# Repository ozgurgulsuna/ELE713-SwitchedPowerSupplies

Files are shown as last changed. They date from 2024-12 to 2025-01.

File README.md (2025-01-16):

# INTRODUCTION

This report presents the design and implementation of a forward converter that operates with an input voltage range of 36-60 V DC, providing a primary output of 5 V at 8 A along with a secondary auxiliary output of 12 V at 4 W. The forward converter is a type of DC-to-DC converter that transfers power during the forward operation of a transformer, making it suitable for applications requiring isolated and regulated outputs.

To achieve precise control over the output voltage, the design employs an analog controller integrated with a feedforward loop. The primary side of the converter utilizes a single switch, while the transformer flux is reset using an additional winding and a diode. This approach ensures efficient operation and prevents magnetic saturation of the transformer core.

In low-voltage, high-current applications, traditional diode-based rectification becomes less efficient due to the voltage drop across the diodes, typically around 0.5 V. To address this inefficiency, synchronous rectification is implemented using MOSFETs at the output. When conducting, a MOSFET with a 10-milliohm resistance produces a voltage drop of only 0.1 V at 10 A, significantly improving overall efficiency.

The printed circuit board (PCB) for this design is manufactured using a photolithography process. This process includes applying a photoresistive UV coating and etching the copper layer using a solution of hydrogen peroxide and hydrochloric acid. The circuit's functionality is thoroughly tested under various load conditions, including overload scenarios and auxiliary load operation, to validate its performance and reliability.

This report further discusses the chosen topology, magnetic design, and key considerations in achieving an efficient, compact, and robust forward converter design.

| Specification | |
|---|---|
| Input Voltage | 36-60 Vdc (Nominal 48Vdc) |
| Main Output Voltage | 5V (min. 4.9V, max. 5.1V) |
| Output Voltage Ripple | 100mV peak-to-peak |
| Main Output Nominal Current | 8A |
| Continuous Output Power | 40W (Main Output) |
| Overload Current | 9A |
| Auxiliary Output Voltage | 12V |
| Auxiliary Output Nominal Current| 0.3A |
| Auxiliary Output Power | 4W |
| Line Regulation | $\pm 0.2$% |
| Load Regulation | $\pm 0.5$% |
| Transient Peak Deviation | 10% of Vout (10% load to 100% @ 48 V) |
| Transient Response Recovery | 200 $\mu sec$ (10% load to 100% @ 48 V) |
| Overall Efficiency @ Full Load  |$\ge$ 80% |

---

# TOPOLOGY
The forward converter is a widely used topology in DC-to-DC conversion, especially for applications requiring electrical isolation and multiple outputs. This topology operates by transferring energy through a transformer during the on-state of the primary-side switch, with energy delivery controlled by the duty cycle of the switch. It is a buck-type converter implemented with the output LC filter structure.

Forward Converter
*Schematic of Forward Converter*

The duty ratio, defined as the proportion of time the primary switch is on during a switching cycle, is a critical parameter in determining the output voltage of the forward converter. The relationship between the input voltage, duty ratio, and transformer turns ratio governs the output voltage. A feedback mechanism ensures the duty ratio is adjusted dynamically to maintain a stable output under varying input and load conditions. In a forward converter, the maximum duty cycle is required to be less than 50% to ensure the transformer reset.

$${V_o \over V_i} = {Ns\over Np}*D$$

At the first cycle when the transistor T is ON, the transformer transfers power to the secondary side, and reset winding is reverse biased. In the second cycle, reset winding resets the transformer and supplies the magnetizing current back to the supply, and the load is supplied by the inductor and capacitor. Reset winding is very important to reset to transformer to prevent core saturation. In our design, we need to add two more windings to the transformer, one is to supply the primary side control circuitry, and another is to create the required 12V auxiliary supply.

The forward converter design includes a bias supply for the primary side, which provides the necessary power to the control circuitry and auxiliary components. This supply is derived from the bias winding connected to the primary side. The circuit initially starts with a voltage divider and a zener diode. As the bias winding experiences a change in flux, it supplies the rest of the circuit with the required voltage. The output of the bias winding is configured as a rectifier of a forward converter and is regulated with a linear regulator constructed from an NPN transistor. This sets the bias supply to approximately 12 volts.

bias
*Schematic of the Bias Voltage Generation Subcircuit.*

The secondary side of the converter includes an auxiliary output in addition to the primary output. This output is set to 12 volts and is rated for 0.3 amperes, resulting in a 4 W auxiliary output. The auxiliary output is supplied from another auxiliary winding with a forward rectifier output. This output is also regulated using a 12-volt linear regulator and is referenced to the ground of the secondary winding.

aux
*Schematic of the Auxiliary Voltage Generation Subcircuit.*

---

# MAGNETIC DESIGN

Magnetic design is a critical aspect of the forward converter, as it directly impacts efficiency, size, and reliability. The transformer in the forward converter serves two primary purposes: providing electrical isolation and stepping the voltage up or down based on the turn ratio.

A forward converter utilizes a transformer operating in forward mode, meaning that energy is transferred directly through the transformer core during the on-state of the primary switch. Unlike some other topologies, energy is not stored in the core during one cycle and transferred in the next; instead, the transfer is immediate.

The magnetic design is done in a MATLAB script that calculates key parameters for a forward converter, focusing on component sizing and operational constraints. It starts by defining input/output voltage ranges, power requirements, efficiency assumptions, and ripple constraints. The output current and its ripple are calculated to establish operating boundaries.

A significant part of the script focuses on determining the duty cycle range as a function of the transformer turns ratio $$(\N_1/N_2\)$$ and selecting an optimal ratio to ensure the converter operates within specified limits. Transformer design calculations include determining winding turns for primary, secondary, and auxiliary windings while ensuring compliance with voltage and current constraints, such as switch voltage limits. The calculated turn ratios are given in the table below.

| Winding | Turns |
|---|---|
| Primary | 10 |
| Reset | 10 |
| Secondary | 4 |
| Bias | 7 |
| Auxiliary | 7 |

*Selected Turns Ratios.*

The script calculates the magnetizing inductance $$\(L_m\)$$ and evaluates the impact of switching frequency on inductor performance. It also designs the output filter components to meet ripple voltage constraints.

Core selection is supported by area product $$\(A_p\)$$ calculations using various methods, ensuring the chosen core can handle the required flux and thermal limits. Wire gauge and winding distribution are calculated to balance current density and copper usage.

Finally, the script includes a loss analysis, estimating core and copper losses, and evaluating leakage inductance to ensure the design meets efficiency and performance goals. This approach focuses on key aspects of forward converter design while avoiding unnecessary complexity.

The code can be found in [magnetic design folder](%5B02%5D%20Magnetic%20Design/magnetic_design.m).

## TRANSFORMER REALIZATION ##

After evaluating the available cores, calculations are made, and a few candidate cores are chosen based on area product criteria. As a final decision, E30/15/7 3C94 is chosen (by Ferroxcube). There were smaller options; however, this core is favored considering the ease of implementation. Our switching frequency is chosen as 200kHz. At 200kHz, which is moderately high, we used $1 mm^2$ litz wires to avoid the skin effect and proximity effect. For the primary we have 10 turns with no parallel wires, at the secondary, we have 4 turns with 2 parallel wires. The auxiliary winding is winded using 0.2 $mm^2$ litz cable to have lower losses. Reset winding and primary bias circuitry are winded with thin copper cables so that they won't carry high currents. The order of windings is secondary-auxiliary-reset-bias-primary.

<div style="text-align: center;">
  PCB Preprocess
  <p><em>Transformer Windings Drawing</em></p>
</div>

---
# CONTROLLER DESIGN
For the controller, a specific analog integrated circuit, LT1952-1 produced by Analog Devices, is used to implement the controller. LT 1952-1 is a single-switch synchronous forward controller for forward controller designs within the range of 25-500 W. This controller is favored because it has the option to implement synchronous rectification. and high efficiencies can be achieved. LT1952 is the main controller; however, there are 2 more integrated circuits for the essential working of the converter. TL431 is used as a feedback compensator for controlling the output voltage. Moreover, LTC3900 is used for synchronous rectification which takes the SYNC signal from the LT1952-1 with the help of pulse transformer and switches two MOSFETs for improving the efficiency (with the risk of short-circuiting the secondary side MOSFETs).

---
# PRODUCTION AND ASSEMBLED PCB
The printed circuit board (PCB) for this design is manufactured using a photolithography process. This process includes applying a photoresistive UV coating and etching the copper layer using a solution of hydrogen peroxide and hydrochloric acid. The circuit's functionality is thoroughly tested under various load conditions, including overload scenarios and auxiliary load operation, to validate its performance and reliability.

<div style="text-align: center;">
  PCB Preprocess
  <p><em>Final Results of the etched PCB.</em></p>
</div>

<div style="text-align: center;">
  PCB Preprocess
  PCB Preprocess
  <p><em>Assembled PCB</em></p>
	        
</div>

## RESULTS ##
After the design is completed and assembled some measurements are taken. At first, some problems occurred at the current sense pin of the controller, which was due to a grounding problem. We solved it by fixing it. 
cs_fault
*Converter Output in the case of fault.*

After fixing that, tests were continued without synchronous switches which provided an efficiency of around 75%. We activated the synchronous rectification to increase efficiency and obtain better results. At this part, we had some problems with the synchronization and failed the synchronize both switches. However, synchronizing one switch had no disadvantage but a slight improvement so we obtained a  semi-synchronous converter. Forward converter without auxiliary is quite efficient; however, the auxiliary linear regulator creates quite a loss. The results are as follows:

5v_rated
*5V Rated Operation*
Ripple_v1
*Voltage Ripple Measurement*

Efficiency Calculations(@48V):

Only Forward Converter

${Efficiency} = {Pout \over Pin}$ =  $`{(5.15 × 7.21) \over (48.5 × 1.04)}`$ = 0.8602

Forward Converter with 4W auxiliary load

${Efficiency} = {Pout \over Pin}$ =  $`{(5.15 × 7.21 + 4.3) \over (48.5 × 1.04)}`$ = 0.8214

I would like to point out that @60V efficiency gets worse due to auxiliary efficiency. 

---

# CONCLUSION

In conclusion, there are several isolated DC-DC converter topologies with all their advantages
and disadvantages. In this project, forward converter topology is implemented to convert 36-
60V to 5V with the addition of 12V auxiliary voltage. Moreover, the project covers magnetic design, analog design, and feedback design
for isolated DC/DC converters. The design showed that the topology proved to be working;
however, there is still room for improvement in terms of PCB design, feedback design, and
magnetic design. 

---
# APPENDIX

```matlab
close all
clear 
clc
%% Specify project requirements

Vimax = 60;
Vimin = 36;
Vo = 5;
Po = 40;
Vaux = 12;
Paux = 4;

% Choose an estimated efficiency
eff_est = 0.82;

% Choose inductor ripple ratio (ismail wants this)
ripple_ratio = 0.1625;

% Voltage ripple defined by specifications
delta_Vo = 0.1;  % Vpp

Io = Po/Vo;
Io_max = Io + Io*ripple_ratio/2;
Io_min = Io - Io*ripple_ratio/2;

% Auxiliary
Iaux = Paux/Vaux;

%% Duty Range vs Turns Ratio
% We observe the effect of turns ratio on the duty range of our converter
% given the input and output voltage range

% Calculated turns ratio for forward converter
% Vo/Vin = D*N2/N1

N1 = 1;

% We sweep N1/N2 between 1 and 5
N2 = linspace(1,5.9,50);

Dmax_vec = zeros(1,50);
Dmin_vec = zeros(1,50);

% Calculate min and max duty values for all N values
for i=1:50
    d1 = ((N2(i)) * ((Vo+Io*0.05)/Vimin));  % output inductance resistance
    d2 = ((N2(i)) * ((Vo+Io*0.05)/Vimax));
    dmax = max(d1,d2);
    dmin = min(d1,d2);
    Dmax_vec(i) = dmax;
    Dmin_vec(i) = dmin;
end

fig1 = figure;
plot(N2/N1,Dmax_vec);
hold on
plot(N2/N1,Dmin_vec);
% draw a line for the duty cycle limit
plot([0 5.9], [0.39 0.39], 'r--');
% draw a line for n = 2.6
plot([2.6 2.6], [0 0.5], 'r--');
legend
grid minor
title("Duty cycle limits vs N")
legend("D_{max}", "D_{min}")
xlabel("Turns ratio N"), ylabel("Duty cycle")
ylim([0 0.5])
hold off
% exportgraphics(fig1, "../../4-Report/img/DvsN.pdf")

% from the duty ranges we can select 
% Dmax = 0.39  and
% N1/N2 = 2.6

N2  = 1/2.6 ;
Dmax = (Vo+Io*0.05)/Vimin/N2;
%% Transformer Design
% Switch Voltage Limit: 200 V
% Vsw >= Vimax + Vimax*N1/N3 + Vsnub

Vsnub = 10 ;  % approximately
Vsw_max = 120;
N3_min = 1/((Vsw_max - Vimax - Vsnub)/(Vimax*N1));
% Vimax+Vinmax*N1/N3+Vsnub;
% N3_min = (Vsw - Vimax - Vsnub)/Vimax ;

% Dmax should be less than the Dmax level
Dmax_limit = 1/(1+N3_min/N1) ;

% Pick N3 as 1
N3 = 1;
Dmax_limit = 1/(1+N3/N1) ;

%% Determine Lm
clear dmin dmax Dmin_vec Dmax_vec d1 d2 i N
% 
Vin_vec = linspace(60, 36, 50);
D_vec = ((Vo+Io*0.05)*N1./(Vin_vec*N2));
fs = linspace(50e3, 200e3, 50);
Lmvec = zeros(1,50);
% delta_ILm_vec = ones(50, 50);  % Initial guess for delta_ILm, e.g., 0.1 A

%
Lm = 200e-6;
Fsw = 200e3;

% for i = 1:50
%     for j = 1:50
%         Lmvec(j) = Vimin*Dmax/(fs(i)*delta_ILm_vec(j))
%         delta_ILm_vec(i,j) = Vimin*Dmax/(fs(i)*Lmvec(j));
%     end
% end

% plot(fs,delta_ILm_vec)

delta_ILm = Vimin*Dmax/(Fsw*Lm);

% Choose max duty as 0.3900, calculate N
N2 = Vo/(Dmax*Vimin);

% Auxulary winding
N4 = Vaux/(Dmax*Vimin);

% Check switch peak current 
Io_pk_ref = Io_max*N2/N1/0.92;  % eff estimate correct ?
Isw_min = Io_min*N2/N1/0.92;
Isw_peak = delta_ILm+Io_pk_ref;   

% Choose switching frequency
%SOLVE DOUBLE ITERATION TO FIND DELTA IL AND LM 

% Determine the transformer current ripple

% Find required Lm versus Fsw
for i=1:50
    Lmvec(i) = (Vimin*Dmax)/(fs(i)*delta_ILm);
end

fig2= figure;
plot(fs, Lmvec/1e-6);
grid minor
xlabel("Switching Frequency (Hz)"), ylabel("L_m value (H)")
title("Lm for the ripple constraint vs. Fsw")

Ireset = (delta_ILm*(N3/N1)*Dmax)/2*1.83;

Vreset = Vimin;

%% Transformer Design POT-Core
% https://www.tdk-electronics.tdk.com/download/519704/069c210d0363d7b4682d9ff22c2ba503/ferrites-and-accessories-db-130501.pdf
Kw = 0.4;

% Select Core Material (N49)
performance_factor = 20000;

% Area Product Calculation: First Method
J = 5e6; % Current Density (A/m^2)
delta_B = performance_factor/Fsw; % Flux Density Swing (T)
P_trans = Vo*Io + Vaux*Iaux + (Vo*Io + Vaux*Iaux)/eff_est+ Vreset*Ireset; % Transmitted Power (P)

% First Ap is from the lecture notes
% Area Product Calculation: Method-1
display("Method-1")
Ap = ((11.1*Vo*Io/eff_est)/(0.141*delta_B*Fsw))^(1.31)*1e4

% Area Product Calculation: Method-2
display("Method-2")
Ap = ((Vo*Io/eff_est)/(0.014*delta_B*Fsw))^(4/3)*1e4

% Area Product Calculation: Method-3
display("Method-3")
C = 0.71; % Converter Coefficient (Forward Converter)
Ap = P_trans/(C*delta_B*Fsw*J)*1e12

% Area Product Calculation: Method-4
display("Method-4")
Kconv = 0.5;
Ap = Kconv*P_trans/(Kw*Fsw*delta_B*J)*1e12

% Selected RM type Core (RM 8 N49)
Ac = 64e-6;
Aw = 10.8*(17-8.55)/2e6;
Ap_core_rm8 = Ac*Aw*1e12
Al = 2200; % (nH/N^2)

% % Selected RM type Core (RM 7 N49 )
% Ac = 43e-6;
% Aw = 8.4*(14.75-7.25)/2e6;
% Ap_core_rm7 = Ac*Aw*1e12
% Al = 1900; % (nH/N^2)

% Ac = 31.3e-6;
% Aw = 8*(12.6-6.4)/2e6;
% Ap_core_rm6 = Ac*Aw*1e12
% Al = 2400; % (nH/N^2)

% % Selected ETD type Core (E 20/10/6 EF20)
% Ac = 32e-6;
% Aw = 14*(14.1-5.9)/2e6;
% Ap_core = Ac*Aw
 
% % Selected PQ type Core (PQ20/20)
% Ac = 62.1e-6;
% Aw = 14.3*(18-8.8)/2e6;
% Ap_core = Ac*Aw
% Al = 5200 % (nH/N^2)

% % RM 10 N49
% Ac = 98e-6;
% Aw = 12.4*(21.2-10.9)/2e6;
% Ap_core = Ac*Aw*1e12
% Al = 2900; % (nH/N^2)

% 
% % RM 12
% Ac = 146e-6;
% Aw = 16.8*(25-12.8)/2e6;
% Ap_core = Ac*Aw
% Al = 5300; % (nH/N^2)

% % EFD 20/10/7
% Ac = 31e-6;
% Aw = 7.77*2*(15.4-8.9)/2;
% Ap_core = Ac*Aw*1e12
% Al = 910;

% % ETD 34/17/11
% Ac = 97.1e-6;
% Aw = 11.8*2*(25.6-11.1)/2e6;
% Ap_core_ETD = Ac*Aw*1e12
% Al = 2600;

% % P18/11 SER
% Ac = 43.3e-6;
% Aw = (14.9-7.60)/2*7.2/1e6;
% Ap_core_P18 = Ac*Aw*1e12
% Al = 260;

% % EF 25 6 11 N97
% Ac = 67.2e-6;
% Aw = (21.7-9.4)/2*6.2/1e6;
% Ap_core_EF25 = Ac*Aw*1e12
% Al = 4100;

% E30/15/7 3C94
Ac = 60e-6;
Aw = (19.5-7.2)/2*9.7*2/1e6;
Ap_core_E30 = Ac*Aw*1e12
Al = 1900;

% % E20/10/6
% Ac = 32e-6;
% Aw = (14.1-5.9)/2*7*2/1e6;
% Ap_core_E20 = Ac*Aw*1e12
% Al = 1350;

%% Turn Number and Saturation Calculations
% From primary side 
% Vp = N1 dΦ/dt

% Expected operation
Np = (Vimax)*D_vec(1)/(Fsw*delta_B*Ac);
Np = (Vimin)*Dmax/(Fsw*delta_B*Ac)

% At max instance, allow for max B. if turns ratio higher than this, core
% will not saturate.
B_sat = 0.3;

% Min turn numbers, less than that with saturate the core 
Np_min = (Vimax)*0.5/(Fsw*B_sat*Ac) 

Np = 10
Nr = 10

Ns_min = Np*N2
Naux_min = Np*N4

Ns = 4
Na = 10

% Np = 8  PRIMARY
% Nr = 8  RESET
% Ns = 3  SECONDARY
% Na = 6  AUX

% Let's back-calculate the core flux density
% Lm = Np dΦ/i in microhenries
Lm_core = Al*Np*Np*1e-9

% in Tesla
delta_B_core = Lm*delta_ILm/(Np*Ac)

% in Tesla
delta_B_core = Lm_core*delta_ILm/(Np*Ac) 

%% Wire Gauge Calculation
% Determine Cable Length and Type
% https://masteringelectronicsdesign.com/the-rms-value-of-a-trapezoidal-waveform-part-2/
% https://masteringelectronicsdesign.com/how-to-derive-the-rms-value-of-a-triangle-waveform/
% Primary side assume square type voltage

Isw_mean = (Isw_peak+Isw_min)/2;
Isw_rms = Isw_mean*sqrt(Dmax);
Isw_rms = sqrt(Dmax/3*(Isw_peak^2+Isw_peak*Isw_min+Isw_min^2));

Isw_avg = Isw_mean*Dmax

Ipri_rms = Isw_rms;
Isec_rms = sqrt(Dmax/3*(Io_max^2+Io_max*Io_min+Io_min^2))

Ireset_rms = delta_ILm*(N3/N1)*sqrt(Dmax/3);

Iaux_rms = sqrt(Dmax/3*((Iaux*1.2)^2+Iaux^2+(Iaux*0.9)^2))

% Winding Area Distribution

A1 = Ipri_rms*Np
A2 = Isec_rms*Ns
A3 = Ireset_rms*Nr
A4 = Iaux_rms*Na

Atotal = A1 + A2 + A3 + A4

A1 = A1/Atotal
A2 = A2/Atotal
A3 = A3/Atotal
A4 = A4/Atotal

Pri_copper_cs = A1*Kw*Aw/Np*1e6
Sec_copper_cs = A2*Kw*Aw/Ns*1e6
Reset_copper_cs = A3*Kw*Aw/Nr*1e6
Aux_copper_cs = A4*Kw*Aw/Na*1e6

Jp=Ipri_rms/Pri_copper_cs
Js=Isec_rms/Sec_copper_cs
Jr=Ireset_rms/Reset_copper_cs
Ja=Iaux_rms/Aux_copper_cs

%% Litz
% Determine Cable Length and Type

% Set cable diameters:

% https://www.elektrisola.com/en/Litz-Wire/Info
litz_packing_factor = 1.28 ;

% TO DO: winding configuration sec/2 : pri : sec/2

%% Output Filter Calculation

Cf_cross_Lf = (Vo*(1-D_vec(1)))/(Fsw^2*8*delta_Vo) 

Lf = 16e-6 % SRP1265CC-220M reduces to 16 uH @ 10 A
Cf_min = Cf_cross_Lf/Lf

Cf = (5 + 5 + 5)*1e-6 ; % uF

delta_Vo_calculated = ((1-D_vec(1)))/(8*Lf*Cf*Fsw^2)*Vo;

delta_Il_max = ((Ns/Np*Vimax-Vo)*(Dmax)/(Fsw*Lf))
delta_Il = ((Ns/Np*Vimax-Vo)*(D_vec(1))/(Fsw*Lf))
Il_peak = Po/Vo+delta_Il/2

Caux_cross_Laux = (Vaux*(1-D_vec(1)))/(Fsw^2*8*Vaux*0.2);
Laux = 2.2e-6;
Caux_min = Caux_cross_Laux/Laux;
Caux = (5 + 5)*1e-6 ; % uF

delta_Iaux_max = ((Vaux)*(1-Dmax)/(Fsw*Laux))  %% simulation check

%% Power Loss

% Core Loss
% https://elnamagnetics.com/wp-content/uploads/library/Ferroxcube-Materials/3C94_Material_Specification.pdf

% Coefficients (with 95% confidence bounds):
p1 =   8.892e-05;
p2 =     0.01501;
p3 =      -0.775;
p4 =       17.63;

P_density_center = p1.*(B_field_center.*1000.*ripple_ratio).^3 + p2.*(B_field_center.*1000.*ripple_ratio).^2 + p3.*(B_field_center.*1000.*ripple_ratio) + p4; % mT -> kW per m^3
P_center = P_density_center.*(C*D*F*2)*1000 ;% core center volume

P_density_sides = p1.*(B_field_sides.*1000.*ripple_ratio).^3 + p2.*(B_field_sides.*1000.*ripple_ratio).^2 + p3.*(B_field_sides.*1000.*ripple_ratio) + p4; % mT -> kW per m^3
P_sides = P_density_sides.*(((A-B)*F*2*D)+((B-C)*(D-E)*F*2))*1000 ;  % core center volume

P_core = (P_center + P_sides)*2 ; % an error margin of 200 % is given

% Copper Loss for litz wire
% AC losses proximity and skin effect can be ignored
% Length of the wires is estimated from the middle radius

end_winding_pri = 0.265;
end_winding_sec = 0.080;

lenght_pri = primary_cable_count*(2*(C+0.005+primary_cable_diameter/2)+2*(F+0.005+primary_cable_diameter/2));
lenght_sec = secondary_cable_count*(((A+B)/2*2)+(5e-3+F)*2) ;

R_meas_pri = 18e-3;
R_pri = (cu_resistivity*lenght_pri)/(primary_parallel*pi*(primary_cable_diameter/2)^2*primary_parallel/litz_packing_factor);
R_pri = R_meas_pri*lenght_pri/(lenght_pri+end_winding_pri);

R_meas_sec = 102e-3;
R_sec = (cu_resistivity*lenght_sec)/(secondary_parallel*pi*(secondary_cable_diameter/2)^2*secondary_parallel/litz_packing_factor);
R_sec = (R_meas_sec*lenght_sec/secondary_parallel)/(lenght_sec/secondary_parallel+end_winding_sec)

P_cu_pri = R_pri*5.3*5.3;
P_cu_sec = R_sec*1.45*1.45;

P_cu_total = P_cu_pri + P_cu_sec ;

% https://downloads.hindawi.com/archive/2012/635715.pdf
L_leak = (mu0*N_pri^2*((0.00016)*2+((B-C)/2))*(F*E+D*(C+2*(((B-C)/2)))))/(3*2^2*E^2);
```

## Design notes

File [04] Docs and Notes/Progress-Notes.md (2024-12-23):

- RM8 N49 Design (+)
- RM10 N49 Design (-)
- open loop simulation (+)
- Component olanlar listesi
- 0603 Sipariş
- PCB Çizimi
- Trafo Sarılması
- PCB Üretimi
- PCB Üzerine Parçaların Yerleştirilmesi
- PCB Testi

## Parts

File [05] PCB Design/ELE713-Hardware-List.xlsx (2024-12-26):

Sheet: Sheet1
Part Number | Digikey Link | Mouser Link | Türkiye Satıcı Link | Adet | Note/Comment
495-5259-ND | https://www.digikey.com/en/products/detail/epcos-tdk-electronics/B65811J0000R049/3914202 | https://www.mouser.com.tr/ProductDetail/EPCOS-TDK/B65811J0000R049?qs=%2FsLciWRBLmCTXJtOuixVPg%3D%3D | - | 2 | RM8 N49 CORE
495-5262-ND | https://www.digikey.com/en/products/detail/epcos-tdk-electronics/B65812A2203X000/3915527 | https://www.mouser.com.tr/ProductDetail/EPCOS-TDK/B65812A2203X?qs=fWY6JreybtlSEWdNz2ESCw%3D%3D | - | 6 | CLAMP RM 8
495-5268-ND | https://www.digikey.com/en/products/detail/epcos-tdk-electronics/B65812N1008D001/3914215 | https://www.mouser.com.tr/ProductDetail/EPCOS-TDK/B65812N1008D001?qs=%2FsLciWRBLmAhX8H95BubLg%3D%3D | - | 3 | BOBBIN COIL FORMER RM 8
495-5266-ND | https://www.digikey.com/en/products/detail/epcos-tdk-electronics/B65812C2005X000/3915529 | https://www.mouser.com.tr/ProductDetail/EPCOS-TDK/B65812C2005X000?qs=Uha62PnlbFACVqKod%252Bob5A%3D%3D | - | 2 | INSULATING WASHER RM 8
495-5279-ND | https://www.digikey.com/en/products/detail/epcos-tdk-electronics/B65813J0000R049/3914243 | https://www.mouser.com.tr/ProductDetail/EPCOS-TDK/B65813J0000R049?qs=%2FsLciWRBLmAzRqx%2FP15VyA%3D%3D | - | 2 | RM10 N49 CORE
495-5285-ND | https://www.digikey.com/en/products/detail/epcos-tdk-electronics/B65814B2203X000/3915532 | https://www.mouser.com.tr/ProductDetail/EPCOS-TDK/B65814B2203X000?qs=6jHPn5rTOgOwyQzQlqNzNA%3D%3D | - | 2 | CLAMP RM 10
495-5284-ND | https://www.digikey.com/en/products/detail/epcos-tdk-electronics/B65814B2005X000/3915531 | https://www.mouser.com.tr/ProductDetail/EPCOS-TDK/B65814B2005X000 | - | 2 | INSULATING WASHER RM 10
495-5288-ND | https://www.digikey.com/en/products/detail/epcos-tdk-electronics/B65814N1008D001/3914253 | https://www.mouser.com.tr/ProductDetail/EPCOS-TDK/B65814N1008D001?qs=vl78tpqlheehtyrm6TecxQ%3D%3D | - | 2 | BOBBIN COIL FORMER RM 10
1297-750341794CT-ND | https://www.digikey.com/en/products/detail/w%C3%BCrth-elektronik/750341794/22040896 | https://www.mouser.com.tr/ProductDetail/Wurth-Elektronik/750341794?qs=1Kr7Jg1SGW%252B6xH4BgiwnUw%3D%3D | - | 1 | XFMR FWD P-P DC/DC CONV 153UH TH
LT1952EGN-1#PBF-ND | https://www.digikey.com/en/products/detail/analog-devices-inc/LT1952EGN-1-PBF/960984 | https://www.mouser.com.tr/ProductDetail/Analog-Devices/LT1952EGN-1PBF?qs=ytflclh7QUVjPwCPnFQa%2Fw%3D%3D | - | 3 | IC REG CTRLR FWRD CONV 16SSOP
LTC3900ES8#PBF-ND | https://www.digikey.com/en/products/detail/analog-devices-inc/LTC3900ES8-PBF/962810 | https://www.mouser.com.tr/ProductDetail/Analog-Devices/LTC3900ES8PBF?qs=hVkxg5c3xu90E3KYcQK6pg%3D%3D | - | 3 | IC GATE DRVR LOW-SIDE 8SOIC
LT4430ES6#TRPBFCT-ND | https://www.digikey.com/en/products/detail/analog-devices-inc/LT4430ES6-TRPBF/960144 | https://www.mouser.com.tr/ProductDetail/Analog-Devices/LT4430ES6TRPBF?qs=hVkxg5c3xu%252BNUKU4M5kxpg%3D%3D | - | 2 | IC OPTOCOUPLER GATE DRVR SOT23-6
516-2390-5-ND | https://www.digikey.fi/en/products/detail/broadcom-limited/HCPL-M453-000E/1236261 | https://www.mouser.com.tr/ProductDetail/Broadcom-Avago/HCPL-M453-000E?qs=s%252BgfxR24RQ4WeIPwGyRm9Q%3D%3D | - | 2 | OPTOISO 3.75KV TRANSISTOR 6SOIC
296-36511-1-ND | https://www.digikey.com/en/products/detail/texas-instruments/CSD18563Q5A/4307641 | https://www.mouser.com.tr/ProductDetail/Texas-Instruments/CSD18563Q5A?qs=uSgeFhR2uNhOB1DXpy%2F30Q%3D%3D | - | 4 | MOSFET N-CH 60V 100A 8VSON
448-BSC094N06LS5ATMA1CT-ND | https://www.digikey.com/en/products/detail/infineon-technologies/BSC094N06LS5ATMA1/7428069 | https://www.mouser.com.tr/ProductDetail/Infineon-Technologies/BSC094N06LS5ATMA1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 | - | 4 | MOSFET N-CHANNEL 60V 47A 8TDSON
SIR690DP-T1-GE3CT-ND | https://www.digikey.com/en/products/detail/vishay-siliconix/SIR690DP-T1-GE3/6707767 | https://www.mouser.com.tr/ProductDetail/Infineon-Technologies/BSC094N06LS5ATMA1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 | - | 6 | MOSFET N-CH 200V 34.4A PPAK SO-8
MBR0540T3GOSCT-ND | https://www.digikey.com/en/products/detail/onsemi/MBR0540T3G/1477146?s=N4IgTCBcDaILICEBKAGArAFhQFQMwHEQBdAXyA | https://www.mouser.com.tr/ProductDetail/onsemi/MBR0540T3G?qs=3JMERSakebrRxZLCTBZZ9A%3D%3D | - | 5 | DIODE SCHOTTKY 40V 500MA SOD123
1727-4317-1-ND | https://www.digikey.com/en/products/detail/nexperia-usa-inc/BCX55-16-115/1692658 | https://www.mouser.com.tr/ProductDetail/Nexperia/BCX55-10115?qs=me8TqzrmIYW35YnvYvQrng%3D%3D | - | 2 | TRANS NPN 60V 1A SOT89
490-GRM31CR61A107MEA8LCT-ND | https://www.digikey.com/en/products/detail/murata-electronics/GRM31CR61A107MEA8L/16033775 | https://www.mouser.com.tr/ProductDetail/Samsung-Electro-Mechanics/CL31A107MPKNNWE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 | - | 4 | CAP CER 100UF 10V X5R 1206
994-Q4470-CLB |  | https://www.mouser.com.tr/ProductDetail/Coilcraft/Q4470-CLB?qs=BJlw7L4Cy799E8Om4qATXA%3D%3D |  | 1 | Pulse Transformers
1727-2893-1-ND | https://www.digikey.com/en/products/detail/nexperia-usa-inc/BAS516-115/763207 | https://www.mouser.com.tr/ProductDetail/Nexperia/BAS516115?qs=me8TqzrmIYVSb%2FgWSGcf7w%3D%3D |  | 5 | DIODE GEN PURP 100V 250MA SOD523
BAT760DICT-ND | https://www.digikey.com/en/products/detail/diodes-incorporated/BAT760-7/697106 | https://www.mouser.com.tr/ProductDetail/Diodes-Incorporated/BAT760-7?qs=JV7lzlMm3yKDDyO09xoRbQ%3D%3D |  | 4 | DIODE SCHOTTKY 30V 1A SOD323
553-2107-ND | https://www.digikey.com/en/products/detail/pulse-electronics/P0926NL/2265652 |  |  | 1 | PULSE XFMR 1:1:1 300UH
CSD19534Q5A | https://www.digikey.com/en/products/detail/texas-instruments/CSD19534Q5AT/4876343 | https://www.mouser.com.tr/ProductDetail/Texas-Instruments/CSD19534Q5AT?qs=s5SkPsIz10%252BKuhqaIOr9Yg%3D%3D | https://ozdisan.com/Product/Detail/594986/CSD19534Q5A | 4 | MOSFET N-CH 100V 50A 8VSON
KRL1632E-M-R022-F-T5 | https://www.digikey.com/en/products/detail/susumu/KRL1632E-M-R022-F-T5/3738000 |  | https://ozdisan.com/passive-components/resistors/smt-smd-and-chip-resistors/ERJ-8BWFR010V/994866 | 4 | SHUNT 0.022
BZG03C18-M3-08GICT-ND | https://www.digikey.com/en/products/detail/vishay-general-semiconductor-diodes-division/BZG03C18-M3-08/7898725 |  |  | 3 | DIODE ZENER 18V 1.25W DO214AC
BZT52C1213-FDICT-ND | https://www.digikey.com/en/products/detail/diodes-incorporated/BZT52C12-13-F/768854 |  |  | 3 | DIODE ZENER 12V 500MW SOD123
559-PS2801C-1-V-F3-ACT-ND | https://www.digikey.com/en/products/detail/renesas-electronics-corporation/PS2801C-1-V-F3-A/9564881 |  |  | 2 | OPTOISOLATOR 2.5KV TRANS 4SOIC
4423-CMK-R010-1.0CT-ND | https://www.digikey.com/en/products/detail/isabellenhuette-usa/CMK-R010-1-0/16733160 |  |  | 1 | RESISTOR - ISA-PLAN SHUNT, 0.01,
4423-CMP-R025-1.0CT-ND | https://www.digikey.com/en/products/detail/isabellenhuette-usa/CMP-R025-1-0/16836690 |  |  | 1 | RESISTOR - ISA-PLAN SHUNT, 0.025
4423-CMK-R050-1.0CT-ND | https://www.digikey.com/en/products/detail/isabellenhuette-usa/CMK-R050-1-0/16836592 |  |  | 1 | RESISTOR - ISA-PLAN SHUNT, 0.05,
399-A768MS107M1HLAE024CT-ND | https://www.digikey.com/en/products/detail/kemet/A768MS107M1HLAE024/12704540 |  |  | 3 | CAP ALUM POLY 100UF 20% 50V SMD
P16562CT-ND | https://www.digikey.com/en/products/detail/panasonic-electronic-components/35SVPF82M/4204894 |  |  | 2 | CAP ALUM POLY 82UF 20% 35V SMD
1189-2212-ND | https://www.digikey.com/en/products/detail/rubycon/250BXC100MEFC16X25/3564423 |  |  | 1 | CAP ALUM 100UF 20% 250V RADIAL
MC78M12BDTRKGOSCT-ND | https://www.digikey.com/en/products/detail/onsemi/MC78M12BDTRKG/1481467 |  |  | 2 | IC REG LINEAR 12V 500MA DPAK
MC7812CDTRKGOSCT-ND | https://www.digikey.com/en/products/detail/onsemi/MC7812CDTRKG/1481277 |  |  | 2 | IC REG LINEAR 12V 1A DPAK
118-SRP1265CC-220MCT-ND | https://www.digikey.com/en/products/detail/bourns-inc/SRP1265CC-220M/21263821 |  |  | 2 | IND SMD 22UH 10A
732-7427520CT-ND | https://www.digikey.com/en/products/detail/w%C3%BCrth-elektronik/7427520/16909847 |  |  | 1 | CMC 17A 2LN 30 OHM SMD
4587-C2220X225K251TCT-ND | https://www.digikey.com/en/products/detail/holy-stone-enterprise-co-ltd/C2220X225K251T/16895032 |  |  | 2 | CAP CER 2.2UF 250V X7R 2220
4587-C1206X221K202TCT-ND | https://www.digikey.com/en/products/detail/holy-stone-enterprise-co-ltd/C1206X221K202T/16895243 |  |  | 4 | CAP CER 220PF 2KV X7R 1206
18-01550900DRCT-ND | https://www.digikey.com/en/products/detail/littelfuse-inc/01550900DR/16627969 |  |  | 1 | 18-01550900DRCT-ND
5923-0680L5000-05CT-ND | https://www.digikey.com/en/products/detail/bel-fuse-inc/0680L5000-05/10440930 |  |  | 4 | FUSE BRD MNT 5A 125VAC/VDC 2SMD
5923-0679L8000-05CT-ND | https://www.digikey.com/en/products/detail/bel-fuse-inc/0679L8000-05/5844041 |  |  | 4 | FUSE BRD MNT 8A 125VAC/VDC 2SMD
SMD/DIP Çevirici TSSOP16 SSOP16 SO16 SOP16 | - | - | https://www.robotizmo.net/smd-dip-cevirici-tssop16-ssop16-so16-sop16-682 | 2 | SMD/DIP Çevirici

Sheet: Sheet2
Part Number | Digikey Link | Mouser Link | Türkiye Satıcı Link | Adet | Note/Comment
240-2501-1-ND | https://www.digikey.com/en/products/detail/laird-signal-integrity-products/CM3421Y600R-10/935982 |  |  | 1 | CMC 15A 2LN 60 OHM SMD
2156-LM340SX-12-ND | https://www.digikey.com/en/products/detail/rochester-electronics-llc/LM340SX-12/12592712 |  |  | 1 | IC REG LIN 12V 1A DDPAK/TO263-3
495-5080-ND | https://www.digikey.com/en/products/detail/epcos-tdk-electronics/b64290l0647x087/3913556 |  |  | 1 | FERRITE CORE TOROID 2.88UH N87
1727-3861-1-ND | https://www.digikey.com/en/products/detail/nexperia-usa-inc/PMEG2015EJ-115/1157680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 |  |  | 2 | DIODE SCHOTTKY 20V 1.5A SOD323F
PS2801-1ACT-ND | https://www.digikey.com/en/products/detail/cel/PS2801-1-F3-A/770595 |  |  | 1 | OPTOISOLATOR 2.5KV TRANS 4-SSOP
LTC3900ES8#PBF-ND | https://www.digikey.com/en/products/detail/analog-devices-inc/ltc3900es8-pbf/962810 |  |  | 1 | IC GATE DRVR LOW-SIDE 8SOIC
LT1952EGN-1#PBF-ND | https://www.digikey.com/en/products/detail/analog-devices-inc/LT1952EGN-1-PBF/960984 |  |  | 1 | IC REG CTRLR FWRD CONV 16SSOP
HAT2266H-EL-ECT-ND | https://www.digikey.com/en/products/detail/renesas-electronics-corporation/hat2266h-el-e/2328408 |  |  | 2 | MOSFET N-CH 60V 30A LFPAK
LT4430ES6#TRPBFCT-ND | https://www.digikey.com/en/products/detail/analog-devices-inc/LT4430ES6-TRPBF/960144 | https://www.mouser.com.tr/ProductDetail/Analog-Devices/LT4430ES6TRPBF?qs=hVkxg5c3xu%252BNUKU4M5kxpg%3D%3D | - | 1 | IC OPTOCOUPLER GATE DRVR SOT23-6
- | - | - | - | 2 | 13V ZENER
- | - | - | - | 2 | 18V ZENER
- | - | - | - | 3 | 0.5 R 1206
- | - | - | - | 1 | 33 nF 50 V C0G
- | - | - | - | 3 | 0.01R 1206 1W
- | - | - | - | 3 | PNP 45 V 0.1 A SOT23 | BASE ALIMNACAK TSSOP16
- | - | - | - | 1 | 0.1 uF X7R 1206
- | - | - | - | 1 | 182 R 1206
- | - | - | - | 1 | 2.2 R 1206
- | - | - | - | 1 | 1 uF 100V 1206
- | - | - | - | 2 | 7.5 V ZENER
- | - | - | - | 3 | 33 uF 25 V 1206
- | - | - | - | 2 | 100 pF 25V 1206 C0G
- | - | - | - | 1 | 100V 3 A SCHOTTKY
- | - | - | - | 2 | 360 R 1206
- | - | - | - | 2 | 365 R 1206
- | - | - | - | 1 | 220 pF 200 V 1206
- | - | - | - | 1 | 4.7 kR 1206
- | - | - | - | 2 | 10 pF 50 V THT
- | - | - | - | 1 | 4700 pF 50V C0G
- | - | - | - | 1 | 301 kR 1206
- | - | - | - | 2 | 200 kR 1206
- | - | - | - | 2 | 100 kR 1206
- | - | - | - | 1 | 82 kR 1206
- | - | - | - | 1 | 27 kR 1206
- | - | - | - | 1 | 22 kR 1206
- | - | - | - | 1 | 11kR 1206
- | - | - | - | 3 | 10 kR 1206
- | - | - | - | 6 | 220 uF 35 V CAP ALUM
- | - | - | - | 2 | PNP 60 V 1 A SOT89
- | - | - | - | 6 | 1200uF 16V THT ALUM
AP2204K-5.0TRG1DICT-ND | https://www.digikey.com/en/products/detail/diodes-incorporated/ap2204k-5-0trg1/4470810 |  |  | 3 | IC REG LINEAR 5V 150MA SOT23-5
LT1816CS8#PBF-ND | https://www.digikey.com/en/products/detail/analog-devices-inc/lt1816cs8-pbf/891580 |  |  | 3 | IC VOLTAGE FEEDBACK 2 CIRC 8SO
- | - | - | - | 15 | 0.1uF 16V 0603
- | - | - | - | 50 | 0R 603
- | - | - | - | 5 | 20kR 603
- | - | - | - | 20 | 3.3uF 25V 603
- | - | - | - | 5 | 2.43kR 0.5% 603
- | - | - | - | 5 | 1.4kR 0603
- | - | - | - | 5 | 20R 0.1% 0603
- | - | - | - | 5 | Thermistor NTC 10k 0603
- | - | - | - | 10 | 1000pF 50V 603
- | - | - | - | 3 | 61.9kR 0603

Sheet: Sheet3
Part Number | Özdisan Link veya TR | Adet | Note/Comment
495-5259-ND | https://www.digikey.com/en/products/detail/epcos-tdk-electronics/B65811J0000R049/3914202 | 2 | RM8 N49 CORE | DO NOT NEED
495-5262-ND | https://www.digikey.com/en/products/detail/epcos-tdk-electronics/B65812A2203X000/3915527 | 6 | CLAMP RM 8 | DO NOT NEED
495-5268-ND | https://www.digikey.com/en/products/detail/epcos-tdk-electronics/B65812N1008D001/3914215 | 3 | BOBBIN COIL FORMER RM 8 | DO NOT NEED
495-5266-ND | https://www.digikey.com/en/products/detail/epcos-tdk-electronics/B65812C2005X000/3915529 | 2 | INSULATING WASHER RM 8 | DO NOT NEED
495-5279-ND | https://www.digikey.com/en/products/detail/epcos-tdk-electronics/B65813J0000R049/3914243 | 2 | RM10 N49 CORE | DO NOT NEED
495-5285-ND | https://www.digikey.com/en/products/detail/epcos-tdk-electronics/B65814B2203X000/3915532 | 2 | CLAMP RM 10 | DO NOT NEED
495-5284-ND | https://www.digikey.com/en/products/detail/epcos-tdk-electronics/B65814B2005X000/3915531 | 2 | INSULATING WASHER RM 10 | DO NOT NEED
495-5288-ND | https://www.digikey.com/en/products/detail/epcos-tdk-electronics/B65814N1008D001/3914253 | 2 | BOBBIN COIL FORMER RM 10 | DO NOT NEED
1297-750341794CT-ND | https://www.digikey.com/en/products/detail/w%C3%BCrth-elektronik/750341794/22040896 | 1 | XFMR FWD P-P DC/DC CONV 153UH TH | DO NOT NEED
LT1952EGN-1#PBF-ND | https://www.digikey.com/en/products/detail/analog-devices-inc/LT1952EGN-1-PBF/960984 | 3 | IC REG CTRLR FWRD CONV 16SSOP | SPARE / SALVAGE
LTC3900ES8#PBF-ND | https://www.digikey.com/en/products/detail/analog-devices-inc/LTC3900ES8-PBF/962810 | 3 | IC GATE DRVR LOW-SIDE 8SOIC | SPARE / SALVAGE
LT4430ES6#TRPBFCT-ND | https://www.digikey.com/en/products/detail/analog-devices-inc/LT4430ES6-TRPBF/960144 | 2 | IC OPTOCOUPLER GATE DRVR SOT23-6 | SPARE / SALVAGE
TCMT1106 | https://www.ozdisan.com/optoelektronikler/optoelektronikler/transistor-ve-fotovoltaik-cikisli-optokuplorler/TCMT1106 | 4 | OPTOISOLATOR 3.75KV TRANS 4-SOP | ÖZDİSAN
CSD19534Q5A | https://ozdisan.com/power-semiconductors/mosfets/discrete-mosfets/CSD19534Q5A/594986 | 4 | MOSFET DIS.100V 50A N-CH VSONP-8 | ÖZDİSAN
CSD18563Q5A | https://ozdisan.com/guc-yari-iletkenleri/mosfetler/discrete-mosfetler/CSD18563Q5A?gad_source=1 https://ozdisan.com/power-semiconductors/mosfets/discrete-mosfets/CSD18540Q5B/582556 | 6 | MOSFET N-CH 60V 100A 8VSON | ÖZDİSAN
448-BSC094N06LS5ATMA1CT-ND | https://www.digikey.com/en/products/detail/infineon-technologies/BSC094N06LS5ATMA1/7428069 | 4 | MOSFET N-CHANNEL 60V 47A 8TDSON | DO NOT NEED
IRFH5020TRPBF | https://ozdisan.com/power-semiconductors/mosfets/discrete-mosfets/IRFH5020TRPBF/519539 https://karakoyelektronik.com/transistor/bsc320n20ns3g-87663 | 6 | MOSFET N-CH 200V 34.4A PPAK SO-8
MBR0540T3GOSCT-ND | https://ozdisan.com/Product/Detail/38953/MBR0540T1G | 5 | DIODE SCHOTTKY 40V 500MA SOD123 | ÖZDİSAN
BCX56-16,115 | https://ozdisan.com/power-semiconductors/transistors/discrete-transistors/BCX56-16115/344591 | 4 | TRANS NPN 60V 1A SOT89 | ÖZDİSAN
GRM32ER61A107ME20L- | https://ozdisan.com/passive-components/capacitors/smt-smd-and-mlcc-capacitors/GRM32ER61A107ME20L-/406631 | 5 | CAP CER 100UF 10V X5R 1206 | ÖZDİSAN
994-Q4470-CLB |  | 1 | Pulse Transformers | DO NOT NEED
BAS516,115 | https://ozdisan.com/power-semiconductors/diodes-diode-modules-and-rectifiers/general-purpose-diodes/BAS516115/529620 | 20 | DIODE GEN PURP 100V 250MA SOD523 | ÖZDİSAN
SBA140CS_R1_00001 | https://ozdisan.com/power-semiconductors/diodes-diode-modules-and-rectifiers/schottky-diodes/SBA140CSR100001/574222 | 5 | DIODE SCHOTTKY 30V 1A SOD323 | ÖZDİSAN
553-2107-ND | https://www.digikey.com/en/products/detail/pulse-electronics/P0926NL/2265652 | 1 | PULSE XFMR 1:1:1 300UH | SALVAGE
CMS-R020-1.0 | https://ozdisan.com/passive-components/resistors/precision-power-and-shunt-resistors/CMS-R020-1-0/582282 | 4 | RES.SHUNT (6432) 2512 20m Ohms 1% 2.5W AUTO SMT | ÖZDİSAN
1SMA5931_R1_00001 | https://ozdisan.com/power-semiconductors/diodes-diode-modules-and-rectifiers/zener-diodes/1SMA5931R100001/559779 | 5 | DIODE ZENER 18V 1.25W DO214AC | ÖZDİSAN
BZT52C12-TP | https://ozdisan.com/power-semiconductors/diodes-diode-modules-and-rectifiers/zener-diodes/BZT52C12-TP/648661 | 10 | DIODE ZENER 12V 500MW SOD123 | ÖZDİSAN
559-PS2801C-1-V-F3-ACT-ND | https://www.digikey.com/en/products/detail/renesas-electronics-corporation/PS2801C-1-V-F3-A/9564881 | 2 | OPTOISOLATOR 2.5KV TRANS 4SOIC | DO NOT NEED
SMK-R010-1.0 | https://ozdisan.com/passive-components/resistors/precision-power-and-shunt-resistors/SMK-R010-1-0/536411 | 2 | RESISTOR - ISA-PLAN SHUNT, 0.01, | ÖZDİSAN
VMS-R047-1.0-U | https://ozdisan.com/passive-components/resistors/precision-power-and-shunt-resistors/VMS-R047-1-0-U/536795 | 2 | RESISTOR - ISA-PLAN SHUNT, 0.05, | ÖZDİSAN
VR-035V181MG126-T/R | https://ozdisan.com/passive-components/capacitors/aluminum-capacitors/VR-035V181MG126-TR/585021 | 4 | CAP.EL.180uF 35V 10x12.6 MM 105C 2000H SMD | ÖZDİSAN
VR-080V470MG126-T/R | https://ozdisan.com/passive-components/capacitors/aluminum-capacitors/VR-080V470MG126-TR/956356 | 4 | CAP.EL.47uF 80V 10x12.60 105C 2000Hrs SMD | ÖZDİSAN
1189-2212-ND | https://www.digikey.com/en/products/detail/rubycon/250BXC100MEFC16X25/3564423 | 1 | CAP ALUM 100UF 20% 250V RADIAL
MC78M12CDTRKG | https://ozdisan.com/integrated-circuits-ics/power-management-ics/linear-voltage-regulators/MC78M12CDTRKG/353490 | 2 | IC REG LINEAR 12V 500MA DPAK | ÖZDİSAN
MC7812CDTRKG | https://ozdisan.com/integrated-circuits-ics/power-management-ics/linear-voltage-regulators/MC7812CDTRKG/603063 | 3 | IC REG LINEAR 12V 1A DPAK | ÖZDİSAN
IHLP5050FDER100M01 | https://ozdisan.com/passive-components/inductors/fixed-inductors/IHLP5050FDER100M01/589695 | 3 | INDUCTOR FIXED 10uH 20% SMD | ÖZDİSAN
SRI1209-100M | https://ozdisan.com/passive-components/inductors/fixed-inductors/SRI1209-100M/530619 | 2 | INDUCTOR POWER 10UH 12X12MM SMD | ÖZDİSAN
118-SRP1265CC-220MCT-ND | https://www.digikey.com/en/products/detail/bourns-inc/SRP1265CC-220M/21263821 | 2 | IND SMD 22UH 10A | DO NOT NEED
732-7427520CT-ND | https://www.digikey.com/en/products/detail/w%C3%BCrth-elektronik/7427520/16909847 | 1 | CMC 17A 2LN 30 OHM SMD | SPARE / SALVAGE
MC20KTB251225 | https://ozdisan.com/passive-components/capacitors/smt-smd-and-mlcc-capacitors/MC20KTB251225/1201518 | 6 | MLCC (5750) 2220 2.2uF 250VDC ±10% X7R | ÖZDİSAN
CL31C221JIHNNNE | https://ozdisan.com/passive-components/capacitors/smt-smd-and-mlcc-capacitors/CL31C221JIHNNNE/523539 | 10 | MLCC (3216) 1206 220pF 1000VDC ±5% C0G (NP0) | ÖZDİSAN
0154010.DR | https://ozdisan.com/circuit-protections/fuse-components/fuses/0154010-DR/612871 | 1 | FUSE BOARD MOUNT 10A 125VDC 2-SMD | ÖZDİSAN
0154005.DR | https://ozdisan.com/circuit-protections/fuse-components/fuses/0154005-DR/669001 | 1 | FUSE BRD MNT 5A 125VAC/VDC 2SMD | ÖZDİSAN
SET1500 | https://ozdisan.com/circuit-protections/fuse-components/fuses/SET1500/473352 | 10 | FUSE SMD 5A 250V 6125 TIME-LAG | ÖZDİSAN
SFE1800 | https://ozdisan.com/circuit-protections/fuse-components/fuses/SFE1800/994485 | 12 | FUSE SMD 8A 125V 2SMD FAST ACTING | ÖZDİSAN
SMD/DIP Çevirici TSSOP16 SSOP16 SO16 SOP16 | - | 2 | SMD/DIP Çevirici | BOUGHT

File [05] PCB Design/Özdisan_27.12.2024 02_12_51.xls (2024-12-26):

 | 27.12.2024
Fatura Adresim
Fatura adresi seçilmedi.
Görsel | Ürün Kodu | Ürün Açıklama | Birim Fiyat | KDV | Adet | KDV Dahil
 | VR-035V181MG126-T/R | CAP.EL.180uF 35V 10x12.6 MM 105C 2000H SMD | 0,7027700 USD | 20,00 % | 4 | 3,37 USD
 | SFE1800 | FUSE SMD 8A 125V 2SMD FAST ACTING | 0,1079700 USD | 20,00 % | 12 | 1,55 USD
 | IHLP5050FDER100M01 | INDUCTOR FIXED 10uH 20% SMD | 1,8785300 USD | 20,00 % | 3 | 6,76 USD
 | BCX56-16,115 | TRANSISTOR DIS.1A 80V NPN SOT89 MED.POWER SMT | 0,0337300 USD | 20,00 % | 4 | 0,16 USD
 | CSD19534Q5A | MOSFET DIS.100V 50A N-CH VSONP-8 | 0,3787900 USD | 20,00 % | 4 | 1,82 USD
 | MC20KTB251225 | MLCC (5750) 2220 2.2uF 250VDC ±10% X7R | 0,4115900 USD | 20,00 % | 6 | 2,96 USD
 | SBA140CS_R1_00001 | DIODE SCHOTTKY 1A 40V SOD323 SMT | 0,0447700 USD | 20,00 % | 5 | 0,27 USD
 | SET1500 | FUSE SMD 5A 250V 6125 TIME-LAG | 0,1079700 USD | 20,00 % | 10 | 1,30 USD
 | VMS-R047-1.0-U | RES.SHUNT (6432) 2512 47m Ohms 1% 4W AUTO SMT | 0,9272500 USD | 20,00 % | 2 | 2,23 USD
 | BZT52C12-TP | DIODE ZENER 500mW 12V ±5% SOD123 | 0,0143600 USD | 20,00 % | 10 | 0,17 USD
 | CMS-R020-1.0 | RES.SHUNT (6432) 2512 20m Ohms 1% 2.5W AUTO SMT | 0,5433800 USD | 20,00 % | 4 | 2,61 USD
 | 1SMA5931_R1_00001 | DIODE ZENER 1.5W 18V ±5% DO214AC (SMA) SMT | 0,1163900 USD | 20,00 % | 5 | 0,70 USD
 | CL31C221JIHNNNE | MLCC (3216) 1206 220pF 1000VDC ±5% C0G (NP0) | 0,1868800 USD | 20,00 % | 10 | 2,24 USD
 | MC7812CDTRKG | IC-7812 REG LINEAR 12V 1A DPAK | 0,1981200 USD | 20,00 % | 3 | 0,71 USD
 | GRM32ER61A107ME20L- | MLCC (3225) 1210 100UF 10VDC X5R | 1,0300200 USD | 20,00 % | 5 | 6,18 USD
 | TCMT1106 | IC-1106 OPTOISOLATOR 3.75KV TRANS 4-SOP | 0,1861400 USD | 20,00 % | 4 | 0,89 USD
 | VR-080V470MG126-T/R | CAP.EL.47uF 80V 10x12.60 105C 2000Hrs SMD | 0,4075600 USD | 20,00 % | 4 | 1,96 USD
 | SMK-R010-1.0 | RES.SHUNT (3216) 1206 10m Ohms 1% 1W AUTO SMT | 1,3434300 USD | 20,00 % | 2 | 3,22 USD
 | 0154010.DR | FUSE BOARD MOUNT 10A 125VDC 2-SMD | 2,6856500 USD | 20,00 % | 1 | 3,22 USD
 | MC78M12CDTRKG | IC-7812 V.REG.+12V 0,5A SMD TO252 (DPAK) | 0,1706300 USD | 20,00 % | 2 | 0,41 USD
 | MBR0540T1G | DIODE SCHOTTKY 500mA 40V SOD123-5 SMD ON | 0,0573600 USD | 20,00 % | 5 | 0,34 USD
 | CSD18563Q5A | MOSFET DIS.100A 60V N-CH 8SON | 0,4628100 USD | 20,00 % | 6 | 3,33 USD
 | BAS516,115 | DIODE 100V 250MA SOD523 | 0,0206300 USD | 20,00 % | 20 | 0,50 USD
 | 0154005.DR | FUSE BRD MNT 5A 125VAC/VDC 2SMD | 2,5118500 USD | 20,00 % | 1 | 3,01 USD
Toplam Tutar Detayı
Toplam Sipariş Tutarı | 41,61 USD
Kargo Fiyatı | 0,00 USD
KDV | 8,32 USD
Genel Toplam | 49,93 USD
Döviz Kuru | 35,31960 TRY
Ödenecek Tutar | 1763,54 TRY
 | Özdisan Elektronik A.Ş. DES Sanayi Sitesi 104 Sokak A07 Blok No : 54 - 56 Yukarı Dudullu / Ümraniye / İstanbul - Türkiye T : +90 216 420 18 82 F : +90 216 466 36 82

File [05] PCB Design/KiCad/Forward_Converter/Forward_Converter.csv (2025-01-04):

Reference | Value | Footprint | Qty
C1,C8,C16 | 2.2nF | 805 | 3
C2,C12,C13 | 100nF | 805 | 3
C3 | OC | 805 | 1
C6,C7,C11 | 2.2uF | -- mixed values -- | 3
C10,C14,C37,C45 | 10u | Capacitor_SMD:C_1210_3225Metric | 4
C15,C18,C20,C22,C27 | 1uF | -- mixed values -- | 5
C17,C26,C30,C31,C33,C39,C42,C44 | 100n | 805 | 8
C19,C23,C25,C32,C35 | 2.2u | Capacitor_SMD:C_2220_5750Metric | 5
C21 | 100pF | Capacitor_SMD:C_1206_3216Metric | 1
C24 | 220pF | Capacitor_SMD:C_1206_3216Metric | 1
C28 | 100p | 805 | 1
C29 | 470p | 805 | 1
C34 | 220p | 805 | 1
C36 | 10n | 805 | 1
R1 | 12k | 805 | 1
R2 | 18k | 805 | 1
R3 | 12R | 805 | 1
R4,R7,R10,R17 | 10k | 805 | 4
R5 | 180k | 805 | 1
R6 | 240k | 805 | 1
R11,R14 | 0R | 805 | 2
R12,R16,R26 | 4.7k | 805 | 3
R13,R30 | 100k | 805 | 2
R15 | 0R | 805 | 1
R18 | 160k | 805 | 1
R19 | 47R | 805 | 1
R20 | 220R | 805 | 1
R21 | 1.2k | 805 | 1
R22 | 360R | 1206 | 1
R23 | 182R | 1206 | 1
R24 | 365R | 1206 | 1
R25,R28 | 25R | 805 | 2
R27,R29 | 22k | 805 | 2
R31 | 8.2k | 805 | 1
R32 | 1k | 805 | 1
R33 | 200k | 805 | 1
R34 | 27k | 805 | 1

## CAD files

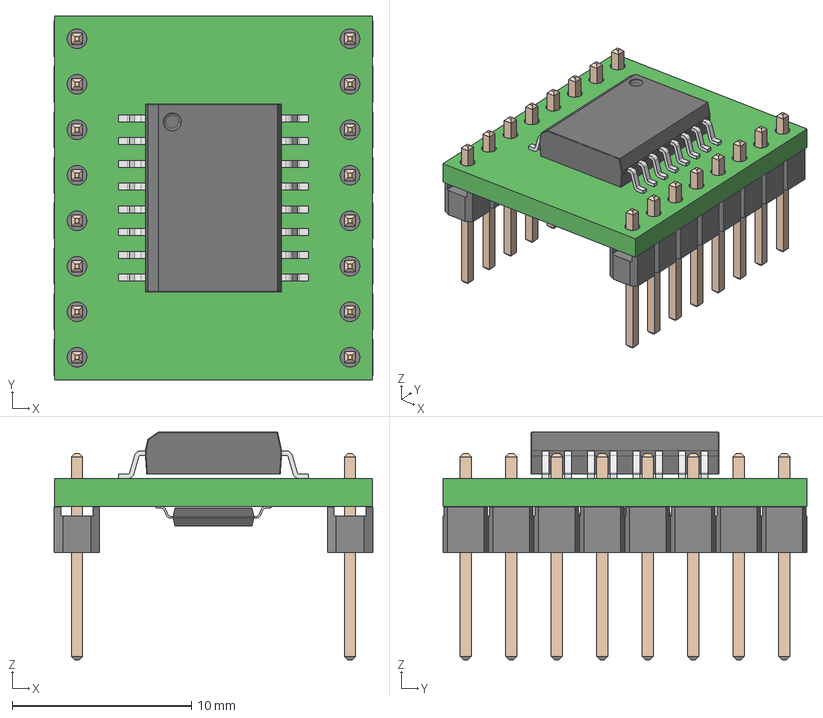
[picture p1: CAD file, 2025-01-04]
[05] PCB Design/3D/SO16 or TSSOP16 to DIL Adapter.step
17.8 x 20.3 x 12.7 mm
Board
User_Library-TSSOP-16_5.1x4.4_pin_TSSOP_tssop_1 x 16
User_Library-TSSOP-16_5.1x4.4_body_TSSOP_TSSOP_5.1x4.5_1
User_Library-SOIC-16-300_SOIC_300_SOIC_10.5X7.6_1
User_Library-SOIC-16-300_pin_SOIC_SO-300_1 x 16
6130xx11121_PIN x 16

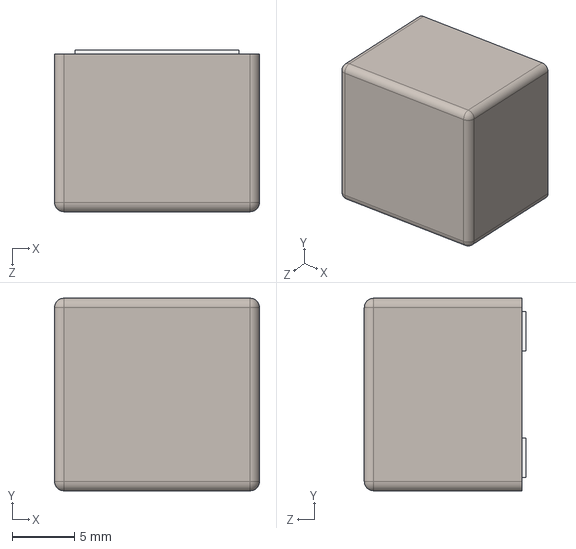
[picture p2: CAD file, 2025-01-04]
[05] PCB Design/3D/SRP1513CA-220M.stp
16.5 x 15.5 x 13.0 mm

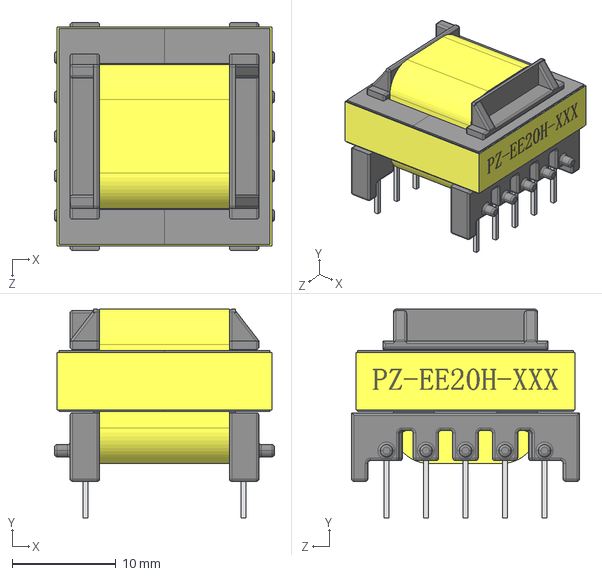
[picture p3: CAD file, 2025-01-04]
[05] PCB Design/3D/EE20H 5+5 transforer.STEP
21.2 x 20.1 x 22.0 mm

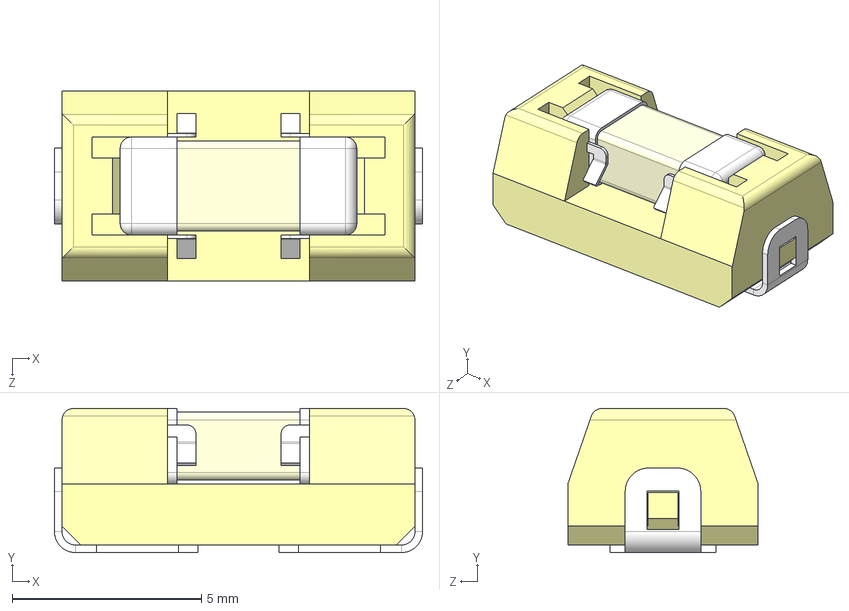
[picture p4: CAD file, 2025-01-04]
[05] PCB Design/3D/0154010.DR.step
9.73 x 3.81 x 5.03 mm

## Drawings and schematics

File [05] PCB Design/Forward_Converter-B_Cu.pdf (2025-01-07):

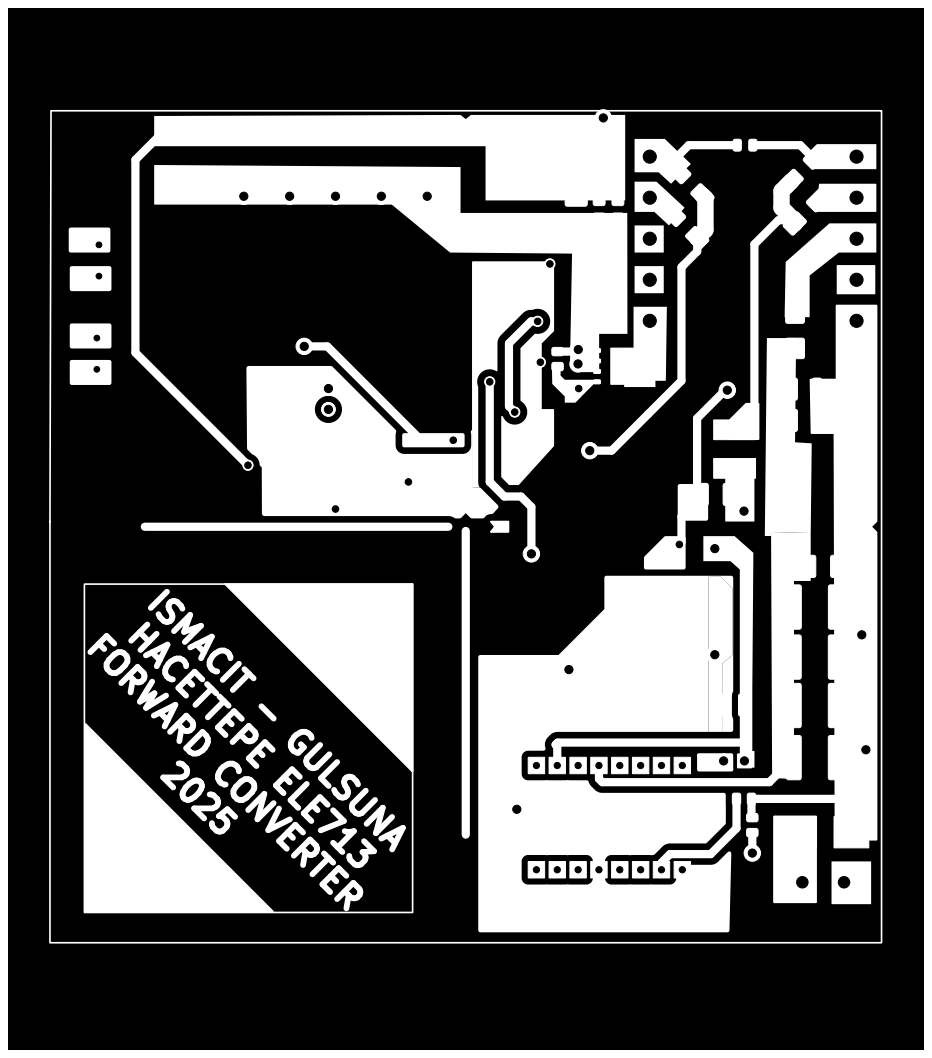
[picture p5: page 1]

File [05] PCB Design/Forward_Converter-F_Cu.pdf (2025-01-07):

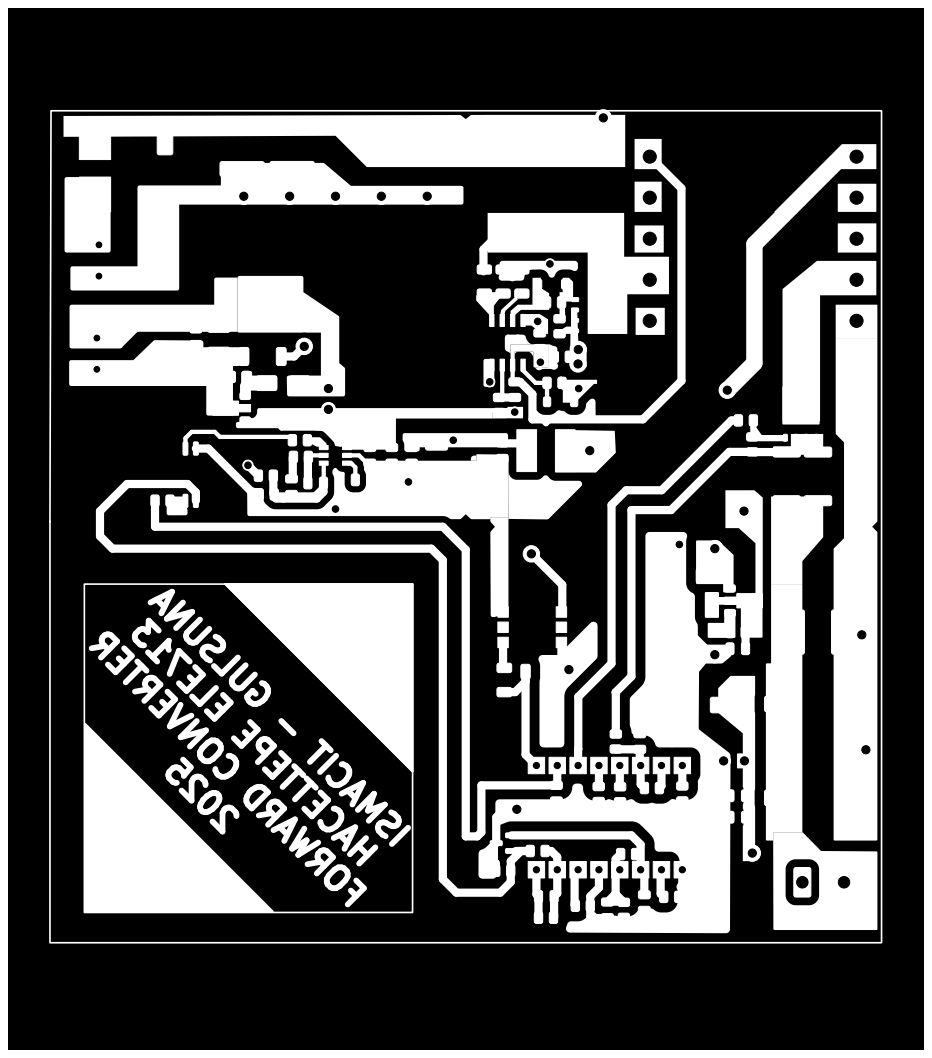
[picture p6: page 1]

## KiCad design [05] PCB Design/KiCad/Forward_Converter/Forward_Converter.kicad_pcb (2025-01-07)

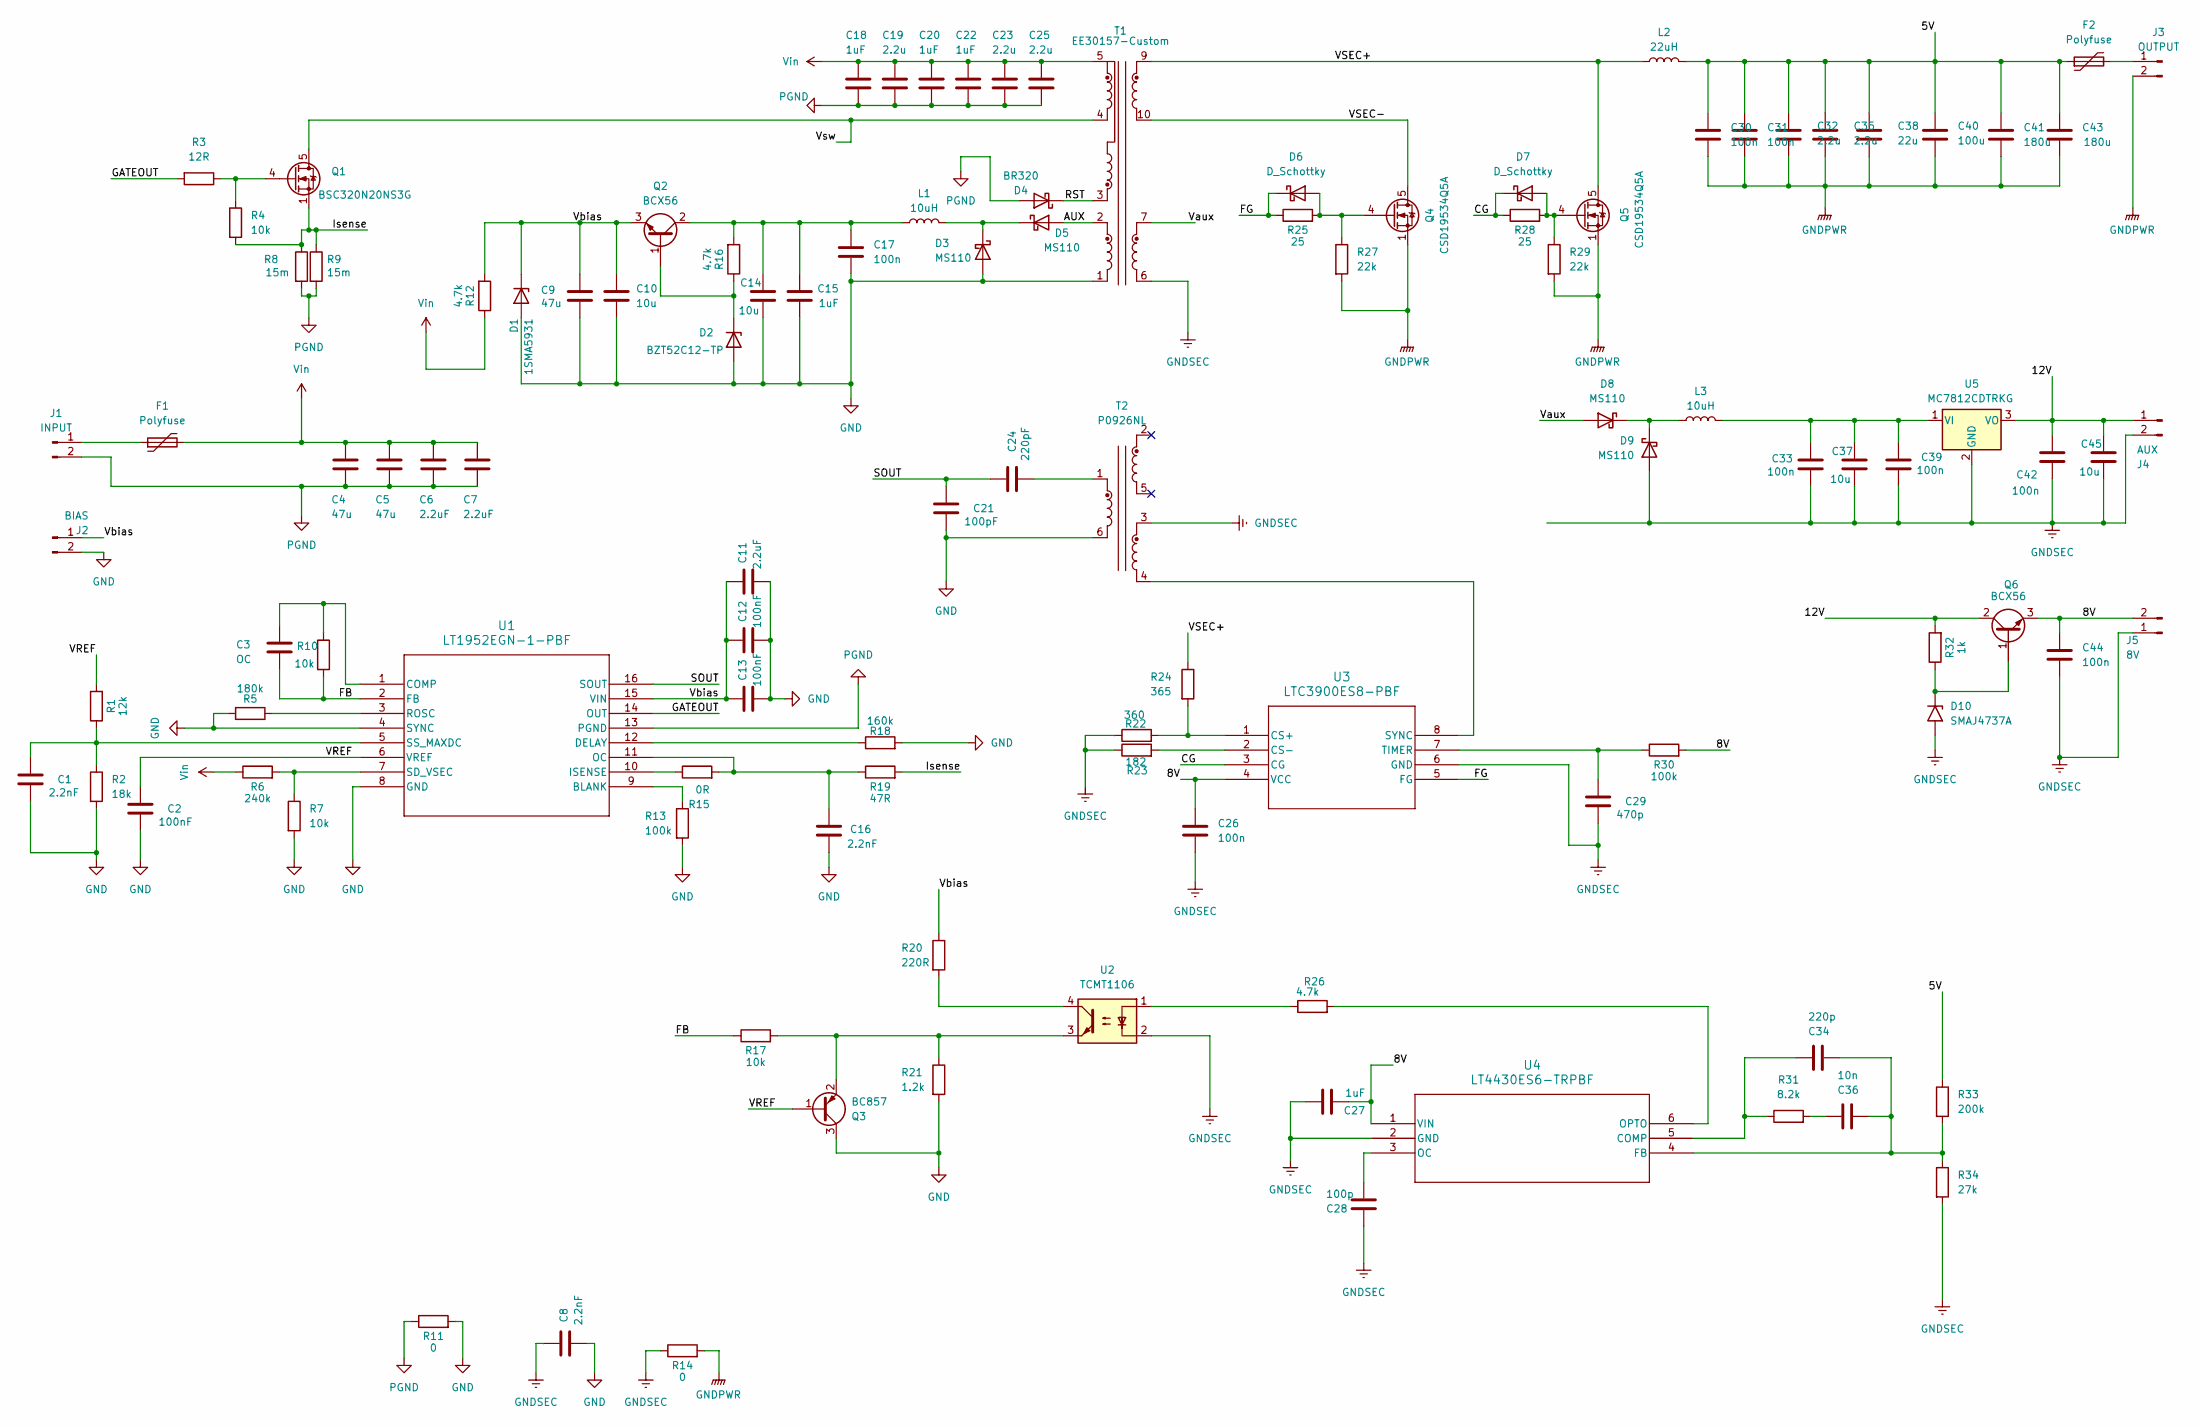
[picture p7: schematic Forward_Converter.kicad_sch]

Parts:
C1, C8, C16: 2.2nF; C_0805_2012Metric
C2, C12, C13: 100nF; C_0805_2012Metric
C3: OC; C_0805_2012Metric
C4, C5, C9: 47u; CP_Elec_10x12.6
C6, C7: 2.2uF; C_2220_5750Metric
C10, C14, C37, C45: 10u; C_1210_3225Metric
C11: 2.2uF; C_0805_2012Metric
C15, C18, C20, C22: 1uF; C_1210_3225Metric
C17, C26, C30, C31, C33, C39, C42, C44: 100n; C_0805_2012Metric
C19, C23, C25, C32, C35: 2.2u; C_2220_5750Metric
C21: 100pF; C_1206_3216Metric
C24: 220pF; C_1206_3216Metric
C27: 1uF; C_0805_2012Metric
C28: 100p; C_0805_2012Metric
C29: 470p; C_0805_2012Metric
C34: 220p; C_0805_2012Metric
C36: 10n; C_0805_2012Metric
C38: 22u; C_1210_3225Metric
C40: 100u; D_SMC
C41, C43: 180u; CP_Elec_10x12.6
D1: 1SMA5931; D_SMA
D2: BZT52C12-TP; D_SOD-123
D3, D5, D8, D9: MS110; D_SMA
D4: BR320; D_SMB
D6, D7: D_Schottky; D_SOD-123
D10: SMAJ4737A; D_SMA
F1, F2: Polyfuse; 0154010.DR
J1: INPUT; PhoenixContact_MSTBA_2,5_2-G-5,08_1x02_P5.08mm_Horizontal
J2: BIAS; PinHeader_1x02_P2.54mm_Vertical
J3: OUTPUT; TerminalBlock_MetzConnect_Type086_RT03402HBLC_1x02_P3.81mm_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
J4: AUX; TerminalBlock_MetzConnect_Type086_RT03402HBLC_1x02_P3.81mm_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
J5: 8V; PinHeader_1x02_P2.54mm_Vertical
L1, L3: 10uH; IND_VLS6045EX-100M-H
L2: 22uH; SRP1513CA8R2M_V2
Q1: BSC320N20NS3G; TDSON-8-1
Q2, Q6: BCX56; SOT-89-3
Q3: BC857; SOT-23
Q4, Q5: CSD19534Q5A; TDSON-8-1
R1: 12k; R_0805_2012Metric
R2: 18k; R_0805_2012Metric
R3: 12R; R_0805_2012Metric
R4, R7, R10, R17: 10k; R_0805_2012Metric
R5: 180k; R_0805_2012Metric
R6: 240k; R_0805_2012Metric
R8, R9: 15m; R_2512_6332Metric
R11, R14: 0; R_0805_2012Metric
R12, R16, R26: 4.7k; R_0805_2012Metric
R13, R30: 100k; R_0805_2012Metric
R15: 0R; R_0805_2012Metric
R18: 160k; R_0805_2012Metric
R19: 47R; R_0805_2012Metric
R20: 220R; R_0805_2012Metric
R21: 1.2k; R_0805_2012Metric
R22: 360; R_1206_3216Metric
R23: 182; R_1206_3216Metric
R24: 365; R_1206_3216Metric
R25, R28: 25; R_0805_2012Metric
R27, R29: 22k; R_0805_2012Metric
R31: 8.2k; R_0805_2012Metric
R32: 1k; R_0805_2012Metric
R33: 200k; R_0805_2012Metric
R34: 27k; R_0805_2012Metric
T1: EE30157-Custom
T2: P0926NL; Pulse_P0926NL
U1: LT1952EGN-1-PBF; SOP16 DIP Adapter
U2: TCMT1106; SOP-4_4.4x2.6mm_P1.27mm
U3: LTC3900ES8-PBF; SO-8_S_LIT
U4: LT4430ES6-TRPBF; TSOT-23_S6_LIT-M
U5: MC7812CDTRKG; TO-252-2

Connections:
/5V: C30.1, C31.1, C32.1, C35.1, C38.1, C40.1, C41.1, C43.1, F2.1, L2.2, R33.1
/8V: C26.1, C27.1, C44.1, J5.2, Q6.3 (E), R30.2, U3.4 (VCC), U4.1 (VIN)
/12V: C42.1, C45.1, J4.1, Q6.2 (C), R32.2, U5.3 (VO)
/AUX: D5.2 (A), T1.2
/CG: D7.1 (K), R28.1, U3.3 (CG)
/FB: C3.1, R10.2, R17.1, U1.2 (FB)
/FG: D6.1 (K), R25.1, U3.5 (FG)
/GATEOUT: R3.2, U1.14 (OUT)
/Isense: Q1.1 (S), Q1.2 (S), Q1.3 (S), R4.2, R8.1, R9.1, R19.2
/RST: D4.1 (K), T1.3
/SOUT: C21.2, C24.2, U1.16 (SOUT)
/VREF: C2.2, Q3.1 (B), R1.2, U1.6 (VREF)
/VSEC+: L2.1, Q5.5 (D), R24.1, T1.9
/VSEC-: Q4.5 (D), T1.10
/Vaux: D8.2 (A), T1.7
/Vbias: C9.1, C10.1, C11.2, C12.2, C13.2, D1.1 (K), J2.1, Q2.3 (E), R12.2, R20.1, U1.15 (VIN)
/Vsw: Q1.5 (D), T1.4
GND: C1.1, C2.1, C8.1, C9.2, C10.2, C11.1, C12.1, C13.1, C14.2, C15.2, C16.1, C17.2, C21.1, D1.2 (A), D2.2 (A), D3.2 (A), J2.2, Q3.3 (C), R2.2, R5.2, R7.2, R11.2, R13.2, R18.2, R21.2, T1.1, T1.8, T2.6, U1.4 (SYNC), U1.8 (GND)
GNDPWR: C30.2, C31.2, C32.2, C35.2, C38.2, C40.2, C41.2, C43.2, J3.2, Q4.1 (S), Q4.2 (S), Q4.3 (S), Q5.1 (S), Q5.2 (S), Q5.3 (S), R14.2, R27.2, R29.2
GNDSEC: C8.2, C26.2, C27.2, C28.2, C29.1, C33.2, C37.2, C39.2, C42.2, C44.2, C45.2, D9.2 (A), D10.2 (A2), J4.2, J5.1, R14.1, R22.1, R23.1, R34.2, T1.6, T2.3, U2.2, U3.6 (GND), U4.2 (GND), U5.2 (GND)
unnamed: C24.1, T2.1
unnamed: C36.2, R31.2
unnamed: D2.1 (K), Q2.1 (B), R16.1
unnamed: D3.1 (K), D5.1 (K), L1.2
unnamed: D6.2 (A), Q4.4 (G), R25.2, R27.1
unnamed: D7.2 (A), Q5.4 (G), R28.2, R29.1
unnamed: D8.1 (K), D9.1 (K), L3.1
unnamed: D10.1 (A1), Q6.1 (B), R32.1
unnamed: F1.1, J1.1
unnamed: F2.2, J3.1
unnamed: Q1.4 (G), R3.1, R4.1
unnamed: C14.1, C15.1, C17.1, L1.1, Q2.2 (C), R16.2
unnamed: Q3.2 (E), R17.2, R21.1, U2.3
unnamed: R20.2, U2.4
unnamed: R26.1, U2.1
unnamed: R13.1, U1.9 (BLANK)
unnamed: C3.2, R10.1, U1.1 (COMP)
unnamed: R18.1, U1.12 (DELAY)
unnamed: R15.1, U1.10 (ISENSE)
unnamed: C16.2, R15.2, R19.1, U1.11 (OC)
unnamed: R5.1, U1.3 (ROSC)
unnamed: R6.2, R7.1, U1.7 (SD_VSEC)
unnamed: C1.2, R1.1, R2.1, U1.5 (SS_MAXDC)
unnamed: R22.2, R24.2, U3.1 (CS+)
unnamed: R23.2, U3.2 (CS-)
unnamed: T2.4, U3.8 (SYNC)
unnamed: C29.2, R30.1, U3.7 (TIMER)
unnamed: C34.2, R31.1, U4.5 (COMP)
unnamed: C34.1, C36.1, R33.2, R34.1, U4.4 (FB)
unnamed: C28.1, U4.3 (OC)
unnamed: R26.2, U4.6 (OPTO)
unnamed: C33.1, C37.1, C39.1, L3.2, U5.1 (VI)
PGND: C4.2, C5.2, C6.2, C7.2, C18.2, C19.2, C20.2, C22.2, C23.2, C25.2, D4.2 (A), J1.2, R8.2, R9.2, R11.1, U1.13 (PGND)
Vin: C4.1, C5.1, C6.1, C7.1, C18.1, C19.1, C20.1, C22.1, C23.1, C25.1, F1.2, R6.1, R12.1, T1.5

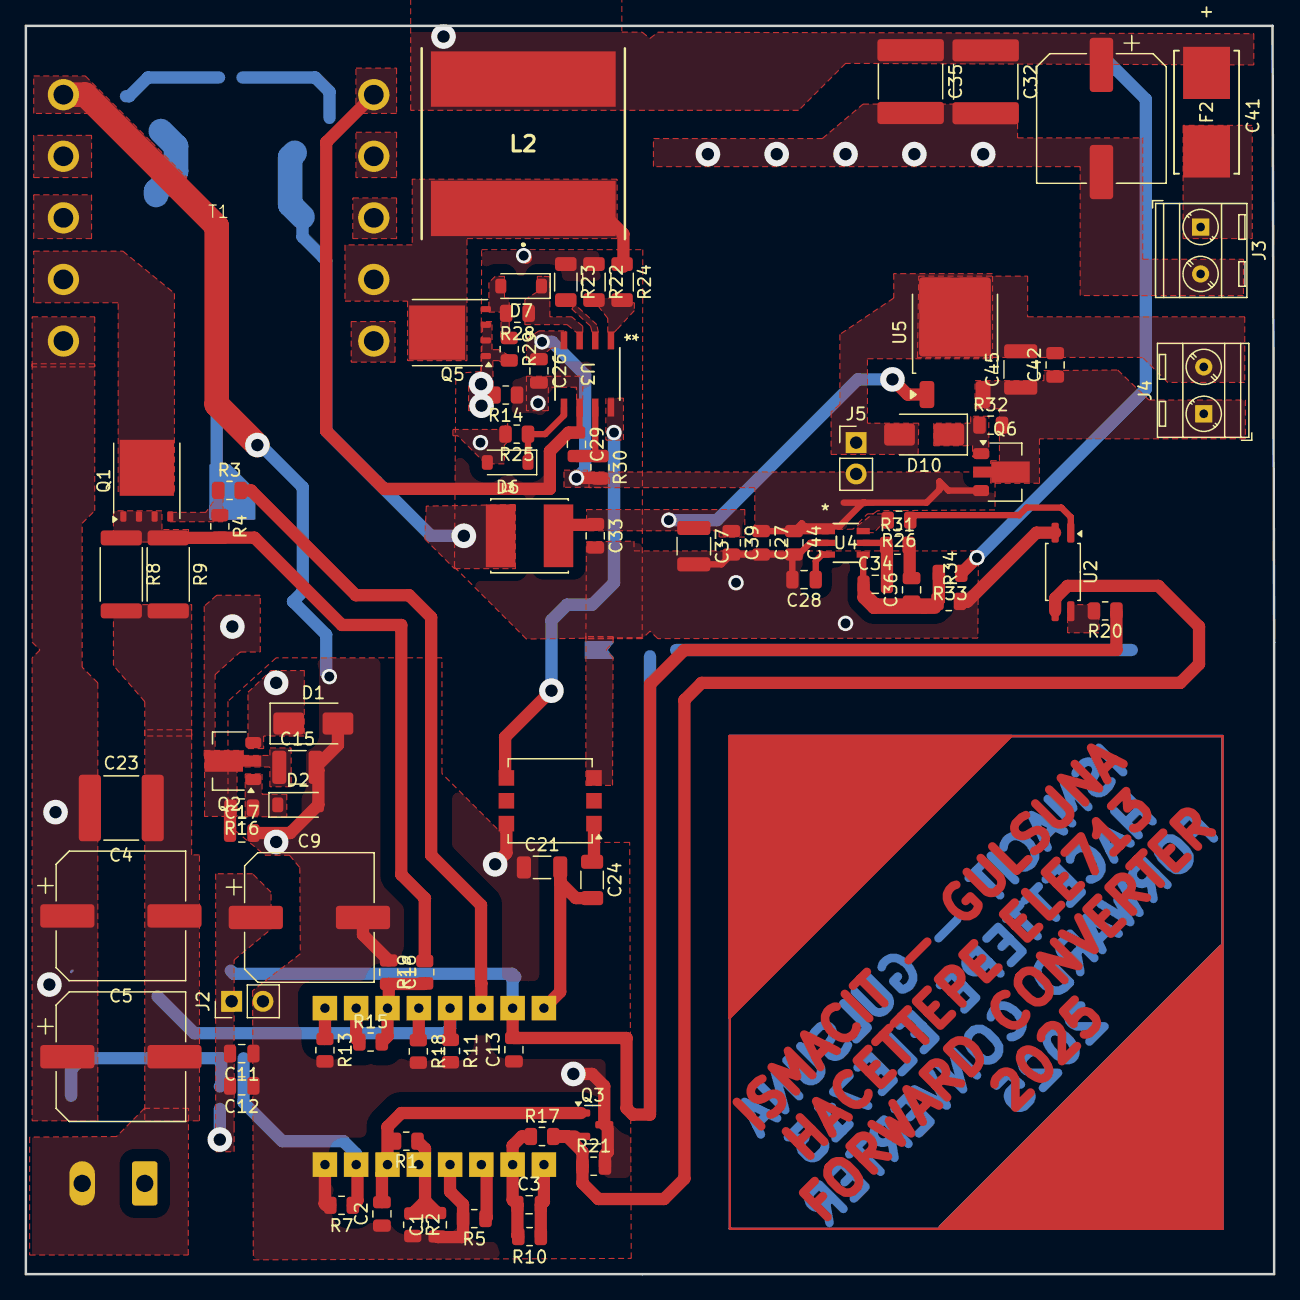
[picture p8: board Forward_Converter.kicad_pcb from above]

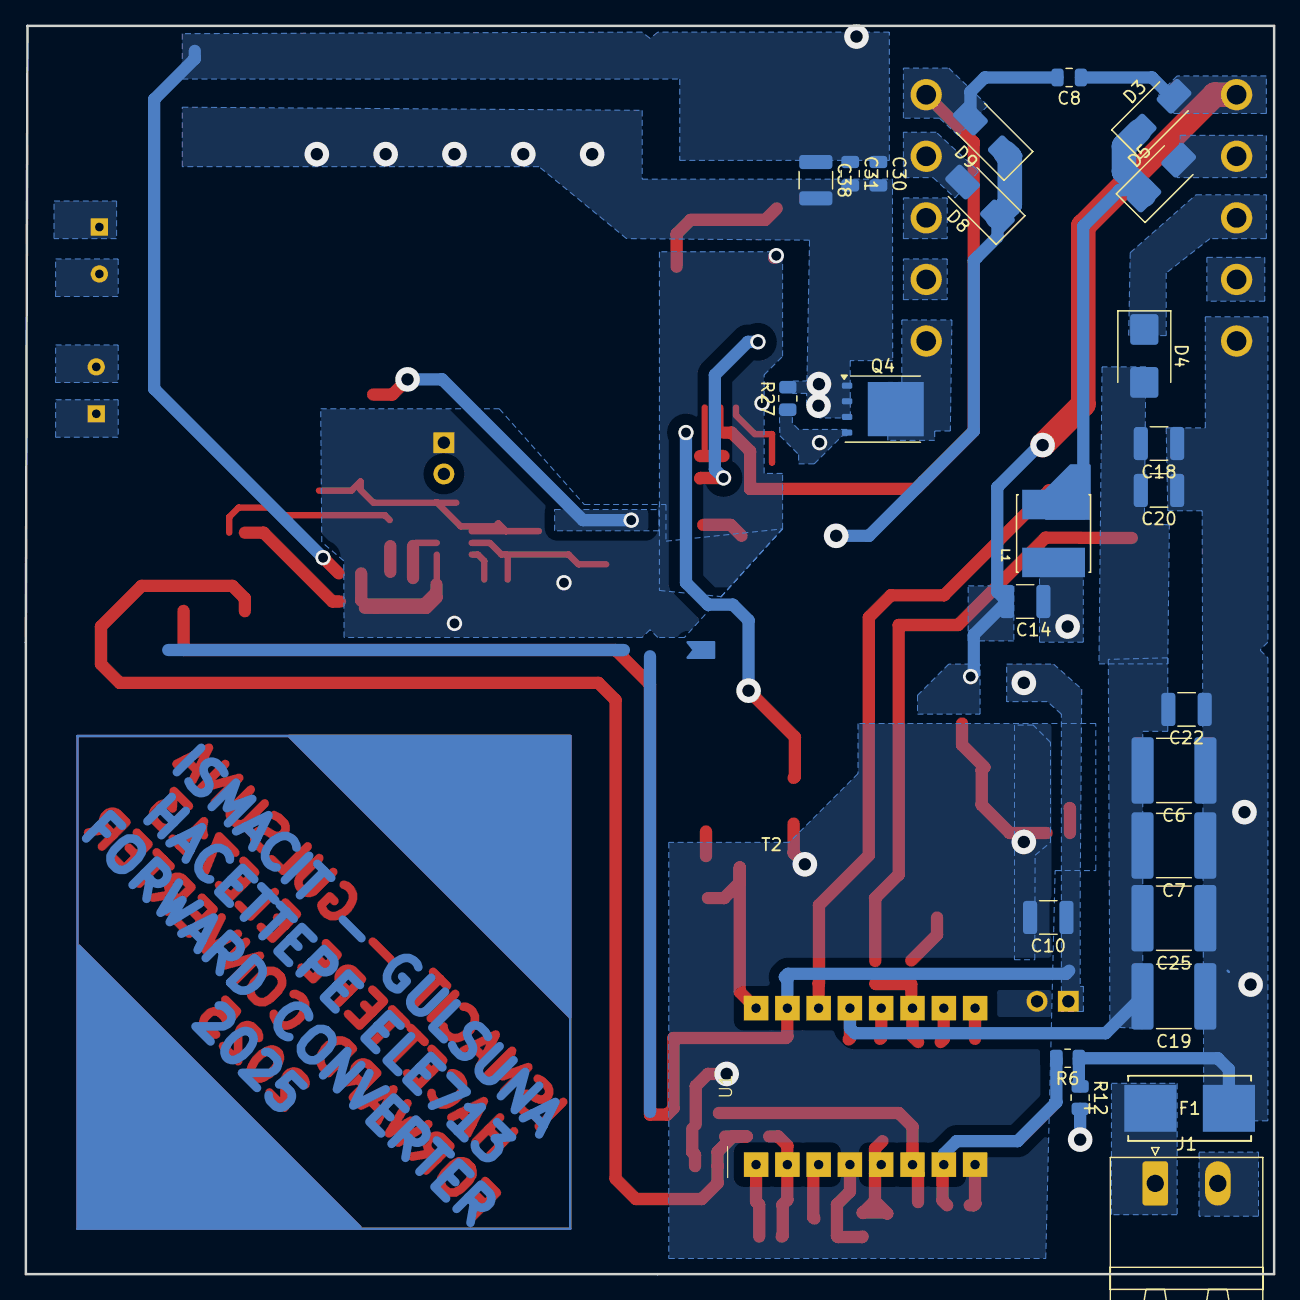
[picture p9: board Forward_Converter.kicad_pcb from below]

Board: 2 copper layers, 101.3 x 101.3 mm, 110 parts (26 on the bottom side), 54 nets.

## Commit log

2024-12-01 [02] % switch current is now an output (just to check)
    Also do not forget to iteratively solve delta_ILm, Lm and fsw relation.
2024-12-21 [02] Magnetic Design Finalized
2024-12-23 [05] Hardware List
    [ELE713-Hardware-List.xlsx]
2024-12-24 Sheet 3 Yerli Parçalar
    Added new sheet for Özdisan components
    [ELE713-Hardware-List.xlsx]
2024-12-25 Update Hardware List
    More components are added
    [ELE713-Hardware-List.xlsx]
2024-12-26 [05] Bom update from local sellers
    [ELE713-Hardware-List.xlsx]
2024-12-26 Added Purchased Components
    Excel files is updated accordingly, purchased components are added.
    [ELE713-Hardware-List.xlsx, Özdisan_27.12.2024 02_12_51.xls]
2024-12-29 [02] Magnetic design, new cores
2024-12-31 PCB Documents Inıtial Commit
    [Forward_Converter.kicad_pcb, Forward_Converter.kicad_sch]
2025-01-01 Schematic and symbols are added
    Transformer footprint is missing and controller card needs attention
    [Forward_Converter.kicad_pcb, Forward_Converter.kicad_sch]
2025-01-01 [02][03] Sim faulty / magnetic design updated
2025-01-02 Schematic update
    IC's are updated, transformer is added
    [Forward_Converter.kicad_sch]
2025-01-03 Schematic Update
    Almost Complete
    [Forward_Converter.kicad_pcb, Forward_Converter.kicad_sch]
2025-01-03 Schematic Final with footprints
    Layout to be done
    [Forward_Converter.kicad_pcb]
2025-01-04 Layout placement
    Placement is almost complete connections to be completed.
    [0154010.DR.step, EE20H 5+5 transforer.STEP, Forward_Converter.kicad_pcb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]
2025-01-04 [05] schematic with zero percent battery
    [Forward_Converter.kicad_pcb, Forward_Converter.kicad_sch]
2025-01-04 Layout is updated
    Close to the final result
    [Forward_Converter.csv, Forward_Converter.kicad_pcb, Forward_Converter.kicad_sch]
2025-01-07 [05] PCB finalized
    [Forward_Converter.kicad_pcb]
2025-01-10 [05] Sync Resistor added
    Sync Resistor added
    [Forward_Converter.kicad_sch]
2025-01-16 Report Update
    Introduction, Topology and Magnetic Design
2025-01-16 Magnetic Design Report Update
2025-01-16 Magnetic design code added to the report
2025-01-16 Added PCB Images Update

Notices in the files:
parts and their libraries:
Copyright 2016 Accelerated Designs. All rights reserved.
